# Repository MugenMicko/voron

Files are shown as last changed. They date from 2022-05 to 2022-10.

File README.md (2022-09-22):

# Voron Mods

These are mods that I have designed for my V0.1 and Trident.

I hope you find some of them useful:

## [Dragon Burner Toolhead](V0/Dragon_Burner)
V0.1 Toolhead using 2 4010 part cooling fans and a 3010 fan for most hotends including the Dragon High Flow, Rapido High Flow and Revo Voron

## [Rapid Burner Toolhead](V0/Rapid_Burner)
V0.1 Toolhead has been specifically designed for the Rapido UHF and Dragon UHF hotends and uses 2 4010 part cooling fans and a 3010 hotend fan

## [MailBox Toolhead](V0/5015_Toolhead)
V0.1 Toolhead using 1 5015 part cooling fans and a 3010 fan for most hotends including the Dragon High Flow, Rapido High Flow and Revo Voron

## [RoundHouse Extruder](general/RoundHouse)
V0.1 Extruder to complement the 5015 Toolhead using BMG parts

## [RoundAbout Extruder](general/RoundAbout)
V0.1 Extruder to complement the 5015 Toolhead using Orbiter v2.0 parts

## [NozzleWiper](V0/NozzleWiper)
V0.1 Nozzle purge and wipe mod

## [TipTophat](V0/TipTophat)
V0.1 Alternative Tophat for the Voron v0.1 which uses the BOM panels

## [RunoutUnklicky](general/RunoutUnklicky)
Runout UnKlicky Sensor is a filament runout sensor

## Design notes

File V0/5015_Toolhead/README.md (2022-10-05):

# 5015 Toolhead v4 (The Mailbox)

This is a Voron V0.1 toolhead that uses the guts of a 5015 fan for part cooling and incorporates Neopixel RGBW leds. It currently works with the LGX Lite extruder, the [Voron PocketWatch 2](https://github.com/VoronDesign/Pocket-Watch) and the [RoundHouse](https://github.com/waytotheweb/voron/tree/main/general/RoundHouse) and the [RoundAbout](https://github.com/waytotheweb/voron/tree/main/general/RoundAbout) extruders designed specifically for this hotend.

It uses the standard Voron V0.1 X carriage (and the MGN9C mod X carriage), is inspired by the [Mini-AfterSherpa](https://github.com/KurioHonoo/Mini-AfterSherpa).

This toolhead should not lose any X, Z travel. Y axis loss depends on the hotend and bed positioning. The Revo Voron losing none, but larger hotends losing up to ~3mm.

5015_Toolhead
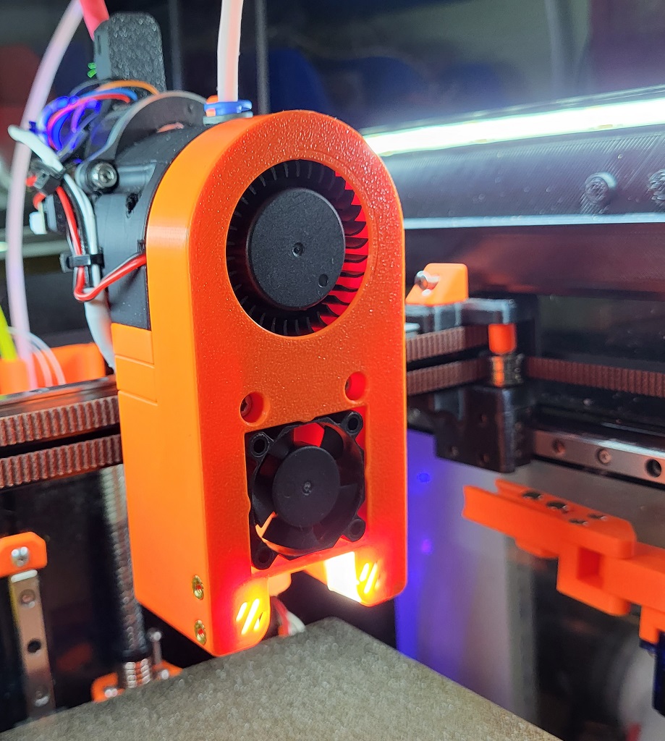
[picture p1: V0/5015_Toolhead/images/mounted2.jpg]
mounted2


### v4 - Front:
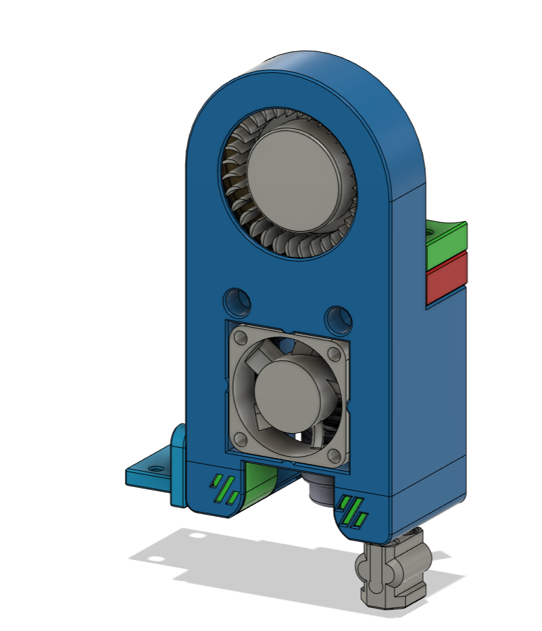
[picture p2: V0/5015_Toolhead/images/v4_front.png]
v4_front


### v4 - Back:
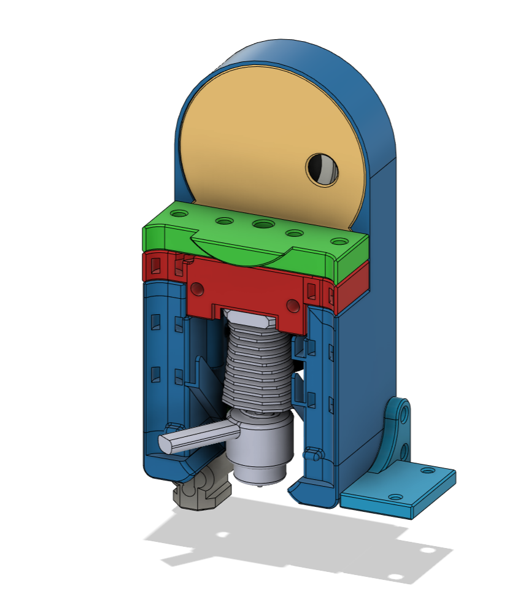
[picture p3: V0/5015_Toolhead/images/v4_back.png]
v4_back


Computation Fluid Dynamics results:

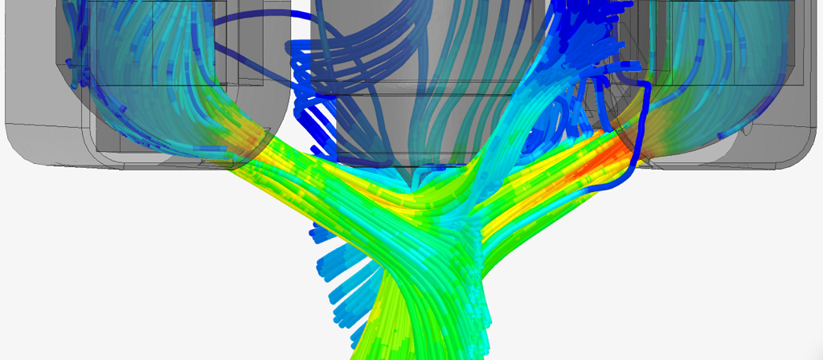
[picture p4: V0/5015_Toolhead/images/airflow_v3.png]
airflow


## Printing:

- Use the Voron defaults and print in ABS or better
- The parts are orientated correctly in the STLs
- The cowl has different variants for choice of probe, or no probe
- Choose the mount for the specific hotend to be used
- If using the [Voron Pocket-Watch 2](https://github.com/VoronDesign/Pocket-Watch) extruder, print the source STL's from the repository, but use the [Guts_p2_x1.stl](STLs/Guts_p2_x1.stl) from this project instead. The Pocket-Watch is [inverted for this toolhead](images/PocketWatch2.jpg). (Note: The PTFE tube will likely pop out of the top of extruder when fully unloading filament as there is no room for the tube retainer)

## BOM:

- 2x M3x35mm SHCS/BHCS (2 for the X carriage mount)
- 2x M3x20mm  SHCS/BHCS (for the hotend/extruder mount)
- 2(4)x Brass heat inserts (2 for cowl hotend mount, 2 optional for ADXL mount)
- 1x 5015 part cooling fan that you are happy to cut to pieces
- 1x 3010 hotend fan (24v recommended)
- 2x Neopixels and wiring (optional)

The cowl variants support a no probe setup, [SlideSwipe magnetic probe](https://github.com/chestwood96/SlideSwipe), [ZeroClick probe](https://github.com/zruncho3d/ZeroClick), [(Un)Klicky Probe](https://github.com/jlas1/Klicky-Probe) and a MiniSlideSwipe using the SlideSwipe mechanism

## Supported Hotends:

- Revo Voron
- Dragon SF/HF
- DragonFly
- Rapido HF / Mellow Crazy Dragon / Dragon UHF (without extender)
- Mellow NF Crazy (/Mozzie)

## Fans:

I am using these fans:

- 24v Blower 5015: [Gdstime](https://www.aliexpress.com/item/32867546212.html)
- 24v Axial 3010: [Gdstime](https://www.aliexpress.com/item/1005002857100082.html)

## Heatsink Thermistor:

Each cowl includes a hole at the top to insert a thermistor. With this in place, klipper can track the temperature of the heatsink to watch for heat creep from the heatbreak. You can have klipper abort and shutdown before your whole toolhead melts! You only need a simple klipper entry for the appropriate pin on your MCU, e.g.:

```
[temperature_sensor Heatsink]
sensor_type: Generic 3950
sensor_pin: expander:PA5
max_temp: 85
```

Klipper will shutdown if the top of the heatsink hits 85C. You can use thermal paste to help keep a bulb thermistor in contact with the heatsink and route the wires through the provided groove, then fit the extruder on top to hold it in place.

## Assembly:

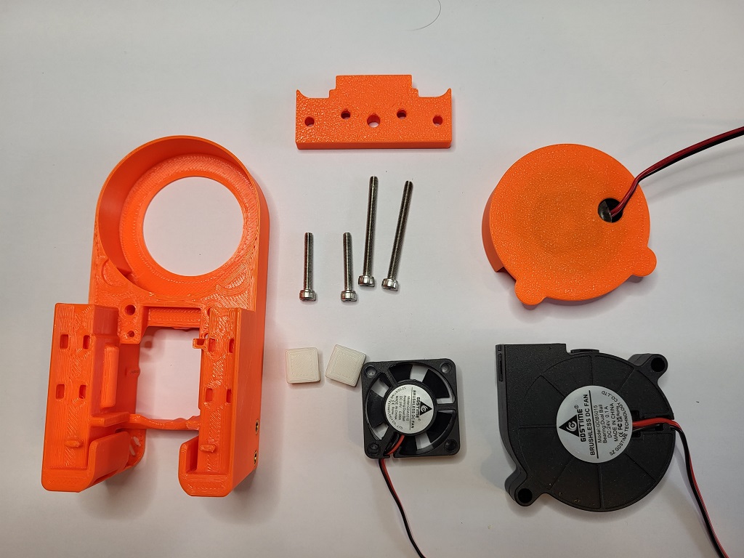
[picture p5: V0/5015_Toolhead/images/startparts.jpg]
startparts


Place brass inserts into the cowl for mounting the hotend and the adxl mount if using this.

Remove the fan duct supports carefully. Check that none of the removed plastic has fallen into the ducts:

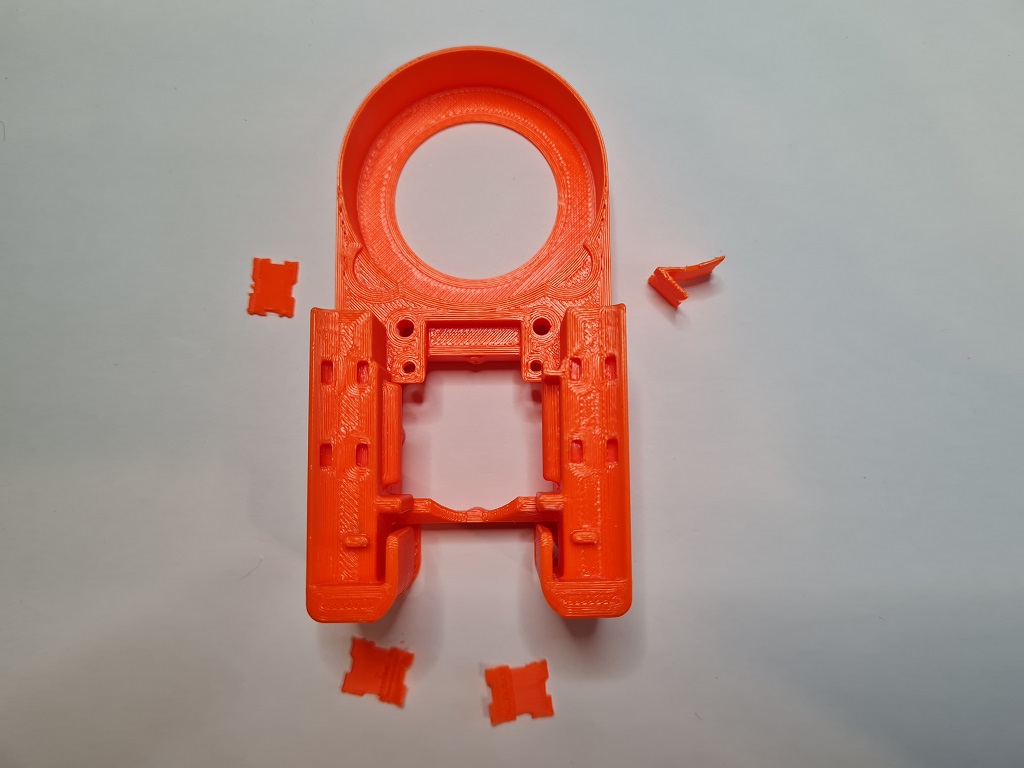
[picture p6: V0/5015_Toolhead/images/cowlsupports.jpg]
cowlsupports

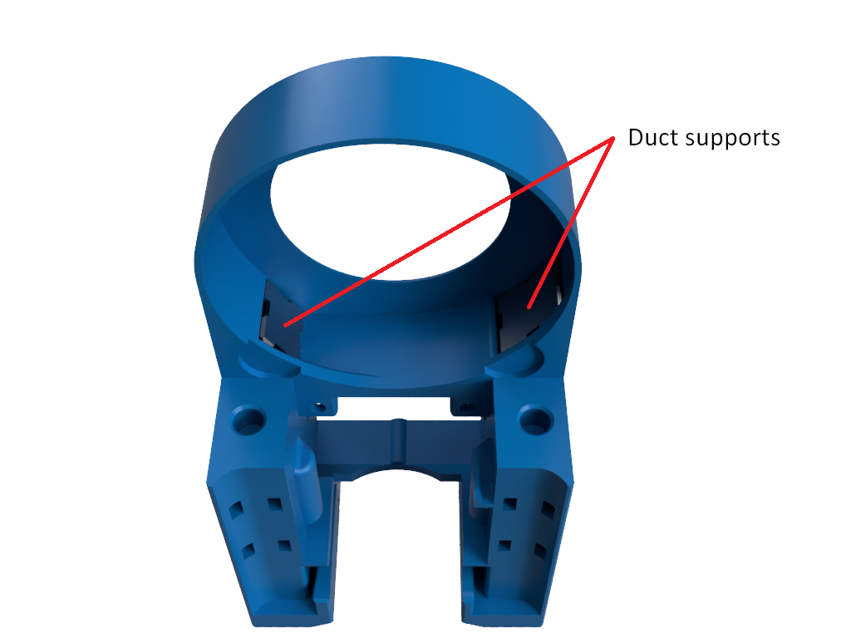
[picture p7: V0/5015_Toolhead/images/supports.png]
supports


The 3010 hotend fan is meant to be press fit. If it's too tight, sand or file the opening but don't force it in otherwise it can deform and the blades will hit the casing. If it's too lose or rattles, use M3 screws to secure it through the top two holes into the cowl. Routing of the fans cables are through the channel provided:

hotendfan
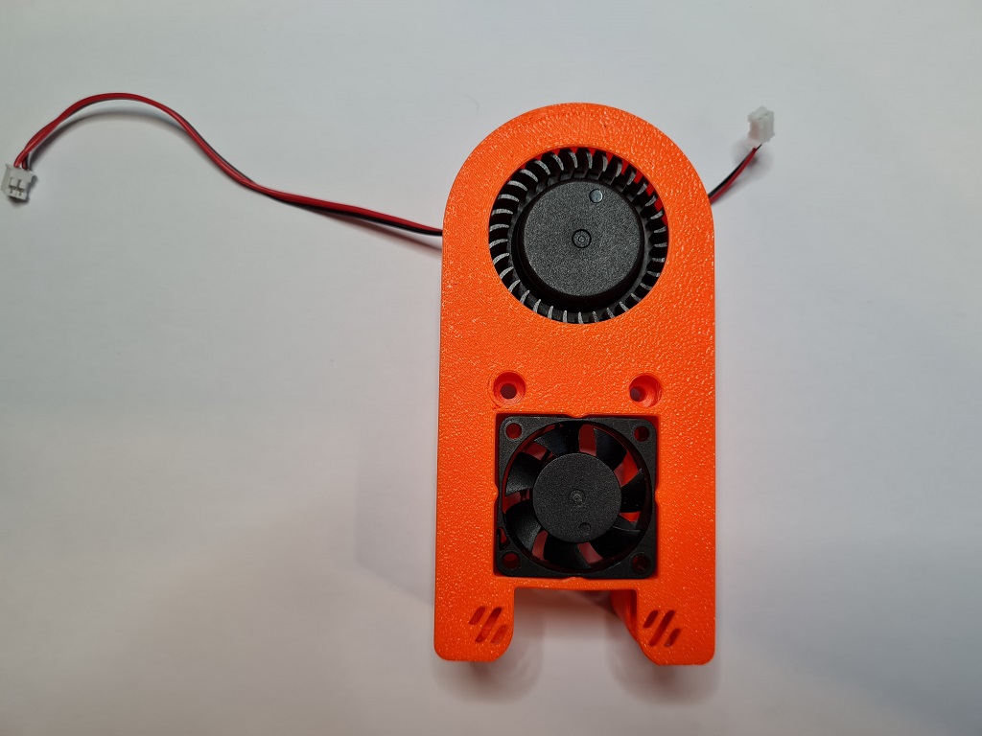
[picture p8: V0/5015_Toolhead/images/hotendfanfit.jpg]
hotendfanfit


You need to remove most of the outer shell of the 5015 fan. Before doing so, please connect the fan to your MCU/toolhead board and ensure that it responds to pmw from klipper.

You need to split the 5015 fan casing in half by poking the tabs on the fan. Once done, take the half with the fan attached and carefully trim off the casing up to the fins. I use side cutters, but a craft knife should work. If more breaks off it shouldn't be a problem. What you want to be left with is a ~35mm circle of casing that matches the diameter of the actual fan. Be very careful not to cut the fan wires, or to manipulate the wires too much as they can easily break from their solder patches (a dab of hot glue helps):

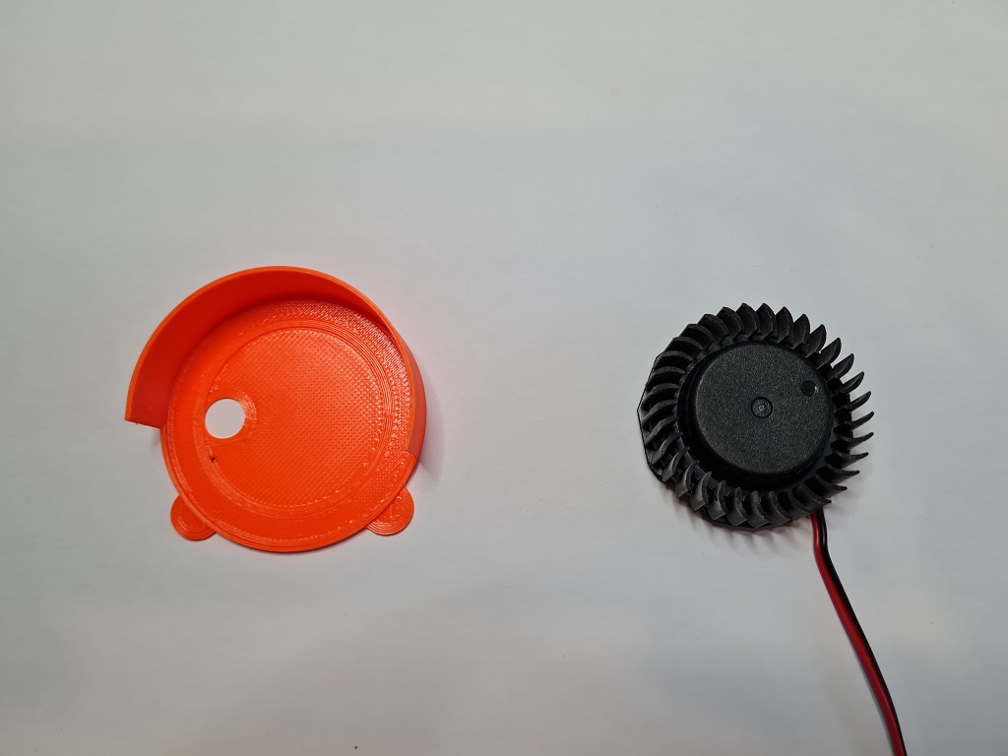
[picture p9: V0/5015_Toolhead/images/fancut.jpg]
fancut


Using VHB tape, cut to fit the back of the fan. You might want to remove any stickers on the back of the fan casing to ensure a good bond:

fantape

Affix the fan to the fan cap by threading the wires through the hole and centre the fan into the middle of the fan cap. It does not need to be 100% central, but the closer the better it will look:

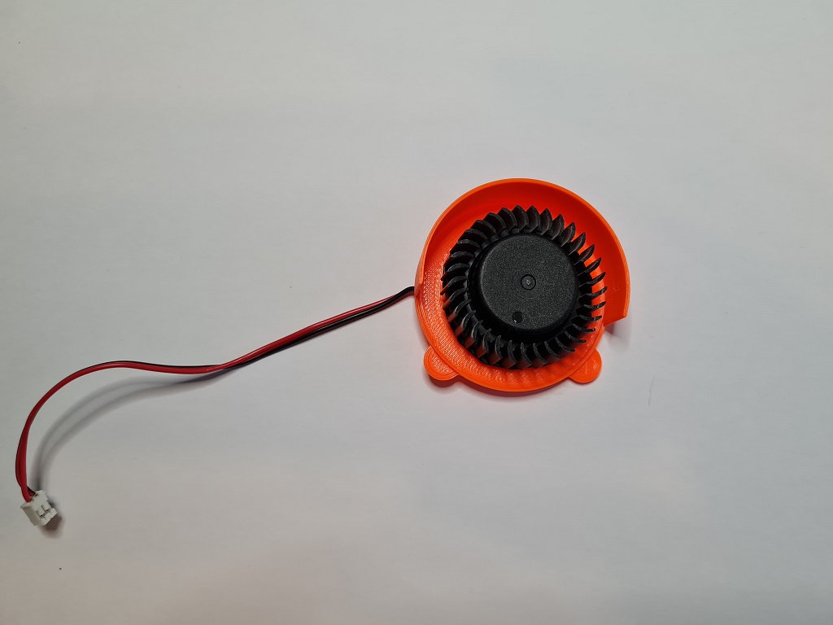
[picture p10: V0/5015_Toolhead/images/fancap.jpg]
fancap


Fit the fan cap onto the cowl and ensure that it sits well without rubbing on the cowl:

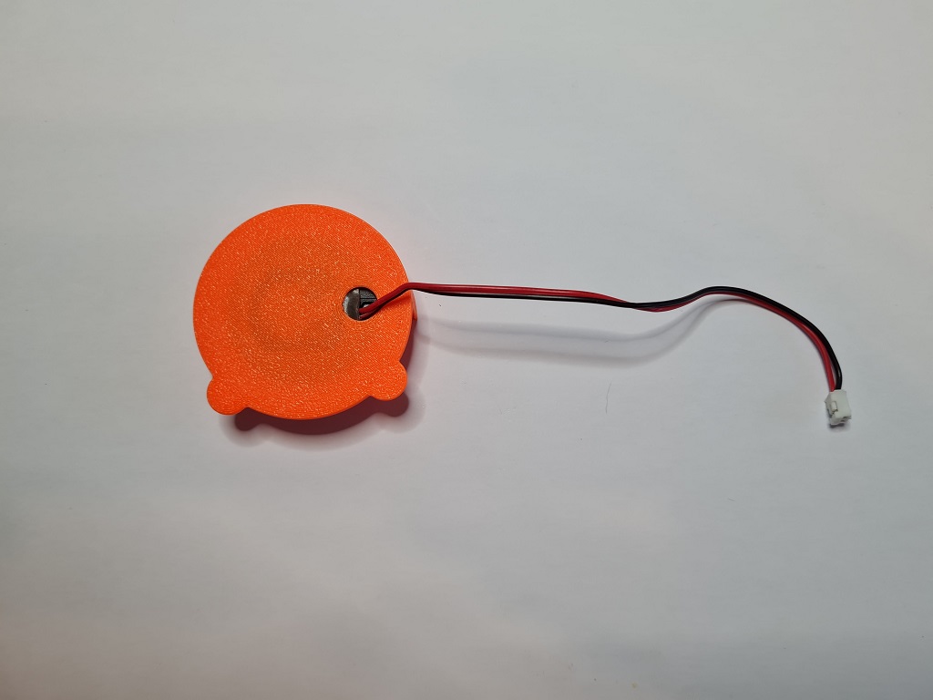
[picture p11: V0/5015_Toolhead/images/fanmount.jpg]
fanmount


The fan cover is a light friction fit and is held in place by the extruder mount:

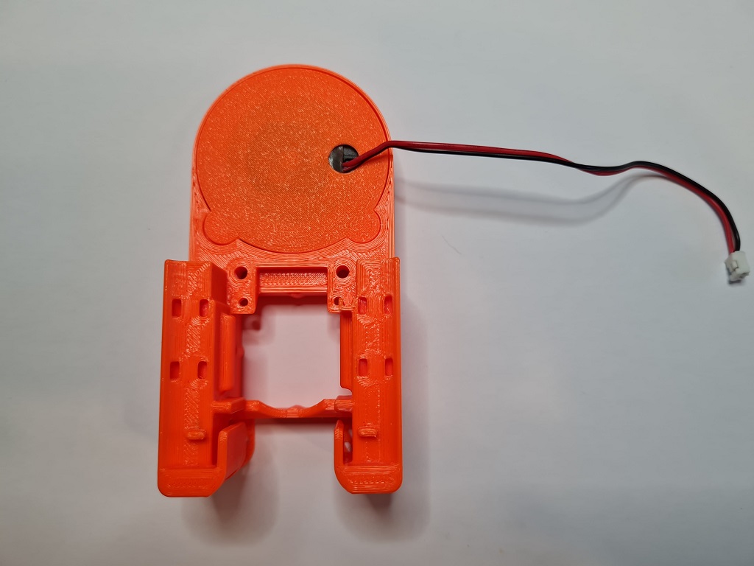
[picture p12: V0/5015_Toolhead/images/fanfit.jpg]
fanfit


If you are going to use Neopixels, remove the two tabs at the inner base of the cowl to expose the Neopixel holes:

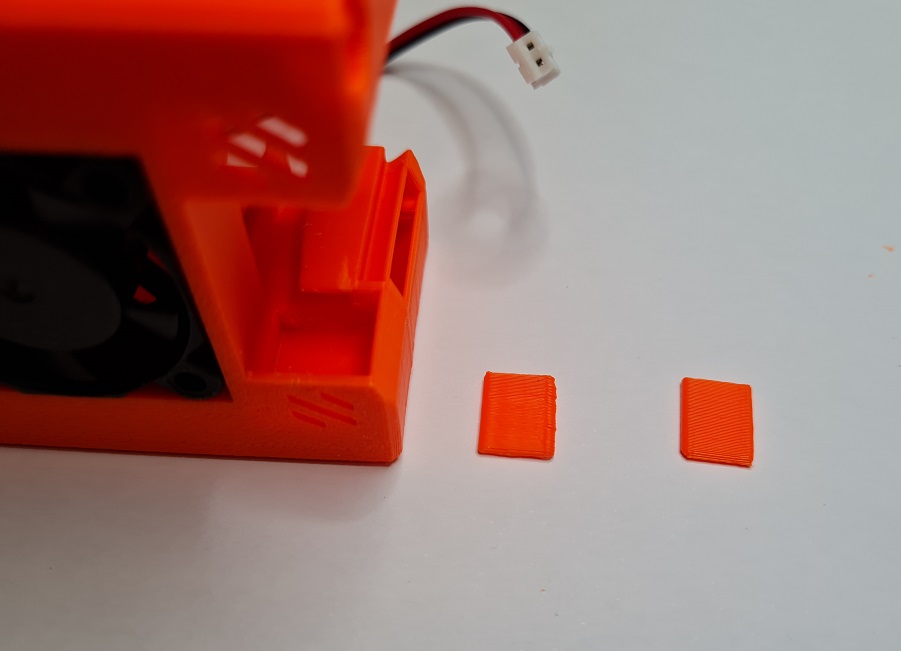
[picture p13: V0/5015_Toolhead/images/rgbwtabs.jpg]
rgbwtabs


Route the Neopixel cable through the provided groove and align with the hole:

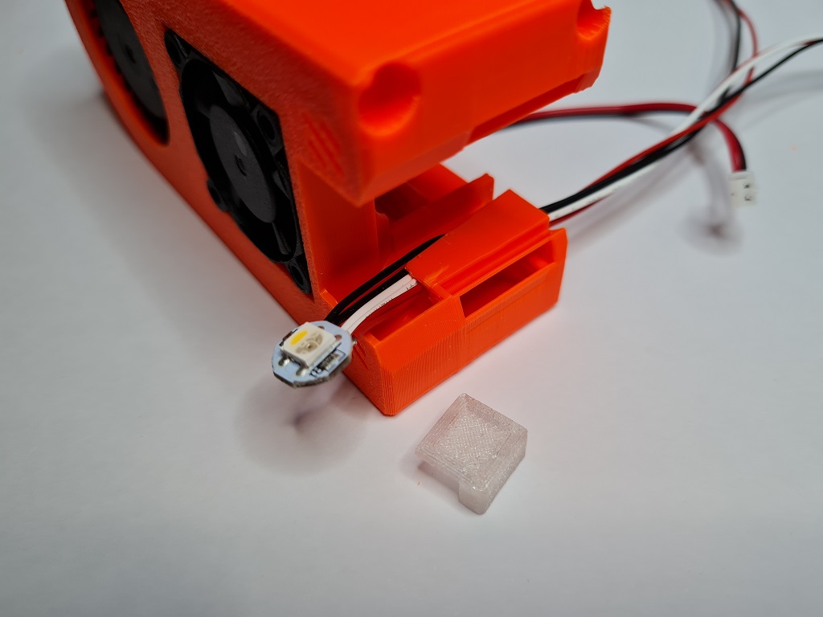
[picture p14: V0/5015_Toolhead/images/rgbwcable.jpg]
rgbwcable


Place the Neopixel diffuser/holder over the top of the Neopixel with the longer sides facing down and the front:

rgbwdiffuser

Push the diffuser/holder into the whole being careful not to dislodge the Neopixel being careful not to leave the cables pinched:

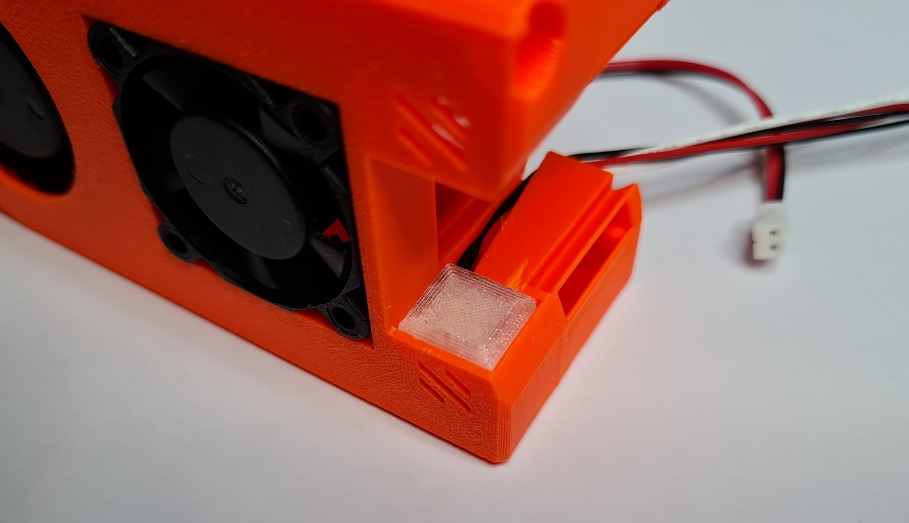
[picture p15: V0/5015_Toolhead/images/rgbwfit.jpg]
rgbwfit


Affix your chosen hotend mount to your hotend:

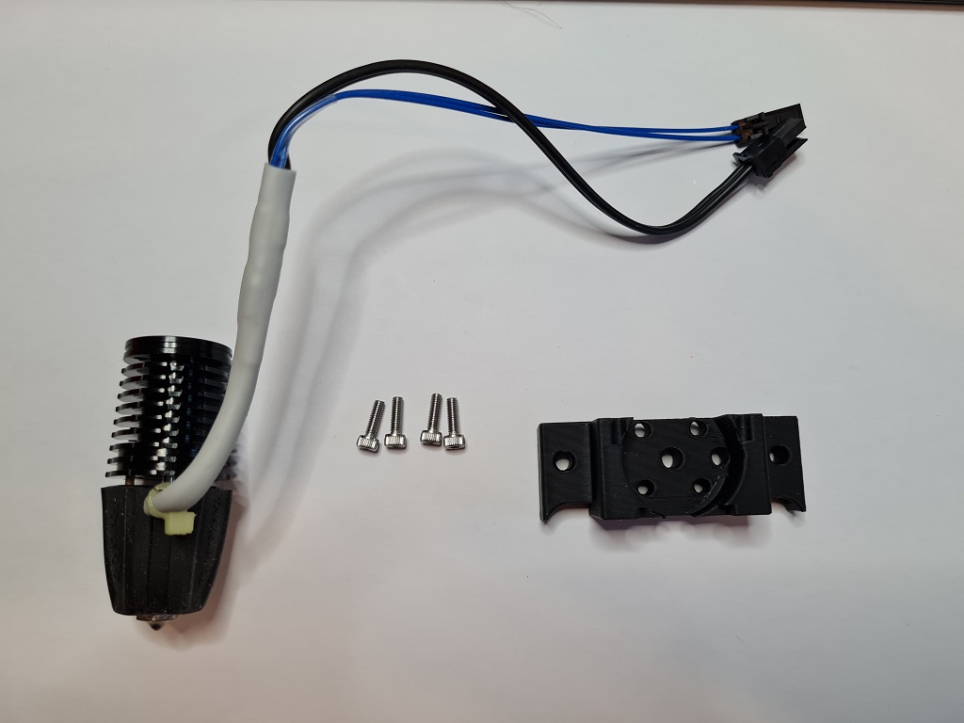
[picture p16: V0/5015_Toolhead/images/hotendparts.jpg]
hotendparts

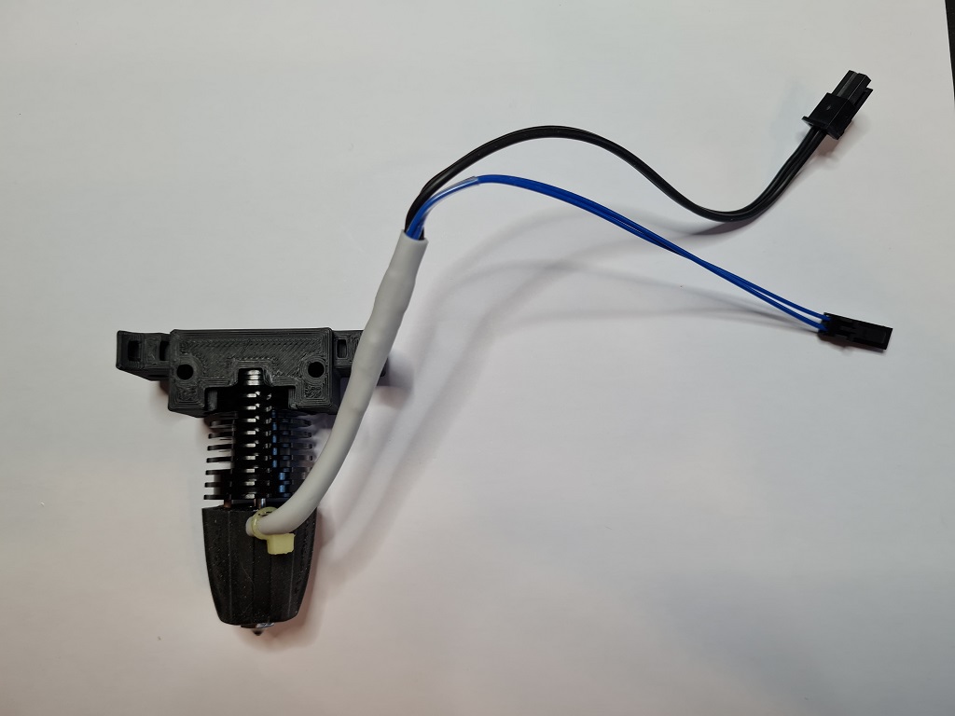
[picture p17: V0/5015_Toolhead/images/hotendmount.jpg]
hotendmount


Affix the extruder mount to the bottom of the extruder:

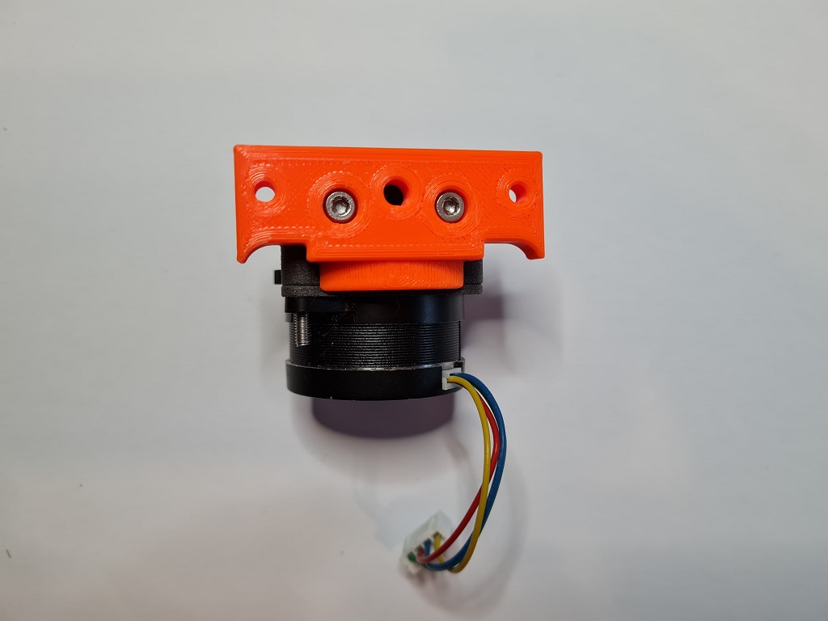
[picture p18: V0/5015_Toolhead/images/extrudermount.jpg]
extrudermount


Mount the extruder on top of the hotend onto the cowl using 2 M3x20 screws to check the assembly:

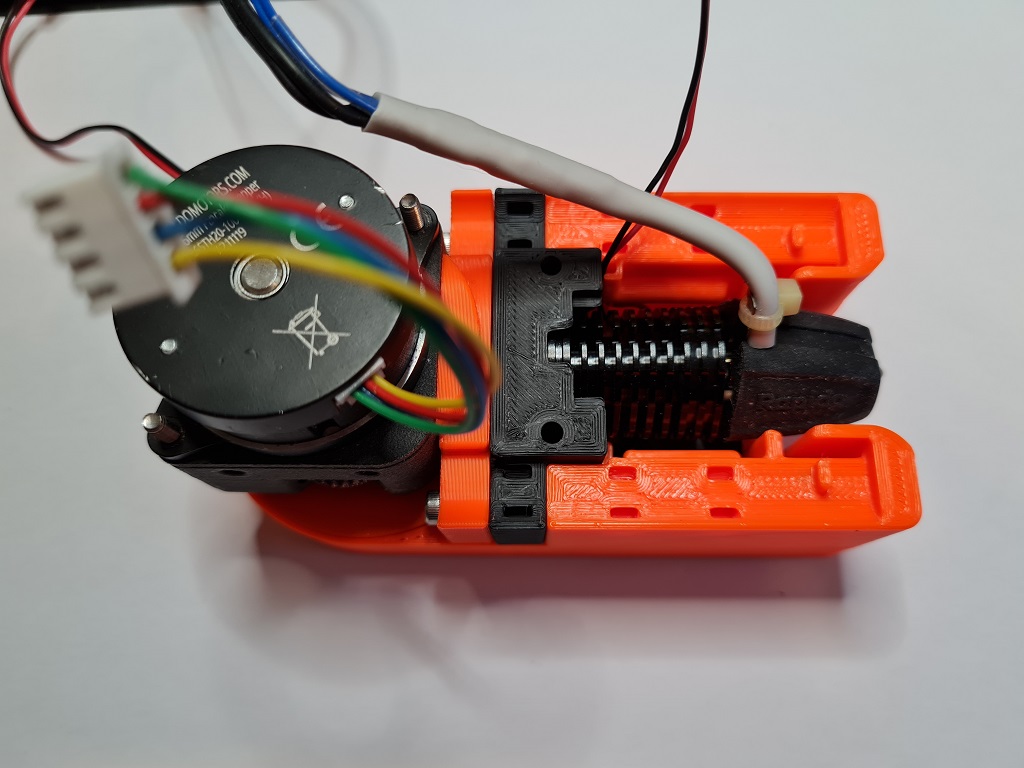
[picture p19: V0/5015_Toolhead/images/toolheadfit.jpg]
toolheadfit


You can now route your cables and secure them to the cable-tie mounts provided.

The following is a complete installation with the [RoundHouse](https://github.com/waytotheweb/voron/tree/main/general/RoundHouse) extruder and a custom hotend:

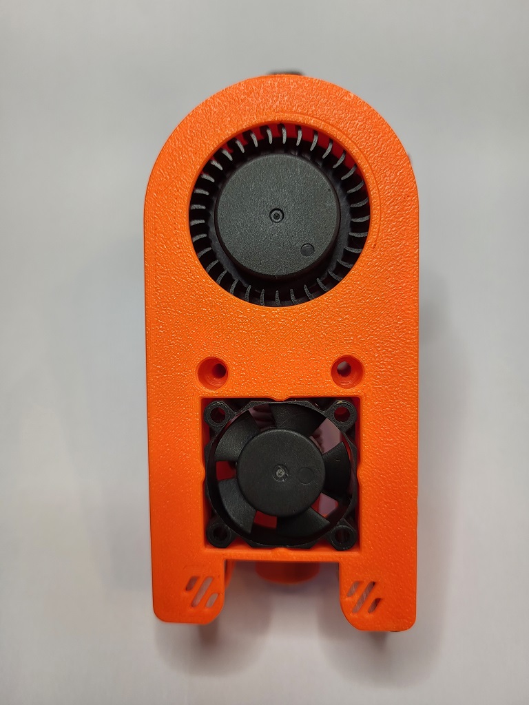
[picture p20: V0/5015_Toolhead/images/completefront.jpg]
completefront


Neopixel cable routing can be seen on these two images:

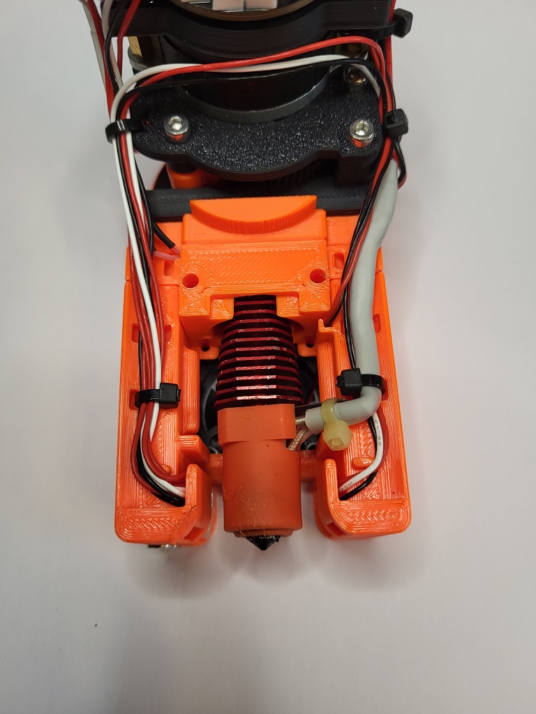
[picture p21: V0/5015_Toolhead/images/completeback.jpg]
completeback

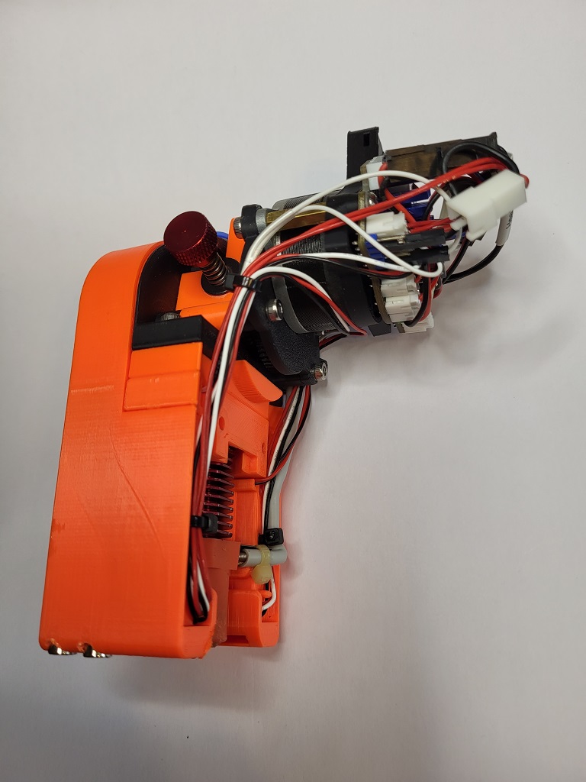
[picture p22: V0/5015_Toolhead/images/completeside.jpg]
completeside


Offer up the cowl and extruder assembly to the X carriage and secure using 2 M3x35mm screws. Be careful not to catch any wires between the surfaces and that when the toolhead moves the X and Y axis endstops are triggered. Also check that the X axis can move completely to the left:

mounted3

Zip-tie the wires at the back of the assembly.

Plugin, test the fans and redo your X offset as it will have changed slightly.

## Neopixels:

Make sure the cables interconnecting the two Neopixels is long enough to loop up both sides of the cowl and above the extruder mount at the rear:
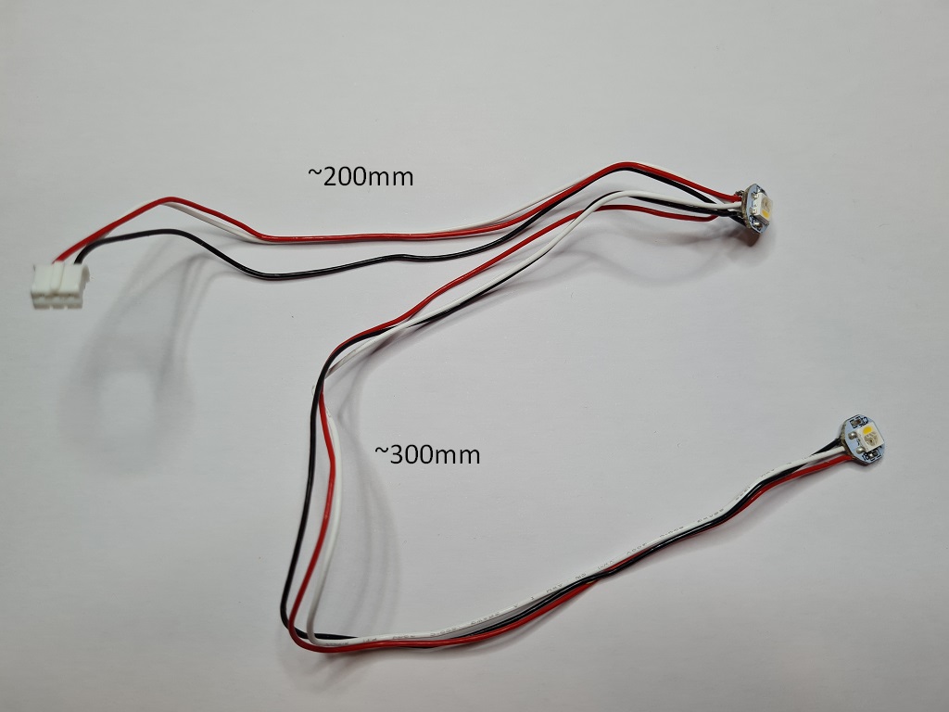
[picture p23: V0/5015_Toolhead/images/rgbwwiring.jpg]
rgbwwiring


For creating the actual wiring, refer to page 46 of the [StealthBurner manual](https://github.com/VoronDesign/Voron-Stealthburner/blob/main/Manual/Assembly_Manual_SB.pdf)

To configure the Neopixels in Klipper, I'd suggest using the [StealthBurner config file](https://github.com/VoronDesign/Voron-Stealthburner/blob/main/Firmware/stealthburner_leds.cfg) and change the following to assign the two Neopixels a wider range of colour options:

```
variable_logo_idx:              "1,2"
variable_nozzle_idx:            "3" # not used
```

## MiniSlideSwipe

This uses the standard [SlideSwipe magnetic probe](https://github.com/chestwood96/SlideSwipe) mechanism, but with a different probe.

There are 2 variants:

- Microswitch

This uses a BOM microswitch. Print [MiniSlideSwipe_Shuttle_Klicky.stl](STLs/MiniSlideSwipe_Shuttle_Klicky.stl). Solder a short piece of stripped wire on the two end posts on the microswitch. Pass the bare wires up into the magnet recesses and push in the microswitch. Push (optionally glue) two magnets with the same polarity into the shuttle.

- Unklicky

This uses a magnet and 2 M3x6mm SHCS/BHCS screws. Print [MiniSlideSwipe_Shuttle_Unklicky.stl](STLs/MiniSlideSwipe_Shuttle_Unklicky.stl) and [MiniSlideSwipe_Probe_Unklicky.stl](STLs/MiniSlideSwipe_Probe_Unklicky.stl). Push one magnet into the probe. Push the probe into the shuttle and partly screw in the M3x6mm SHCS/BHCS screws to the sides of the shuttle. Using 2 pieces of stripped wire, wrap one end around the screw and place the other into the corresponding magnet hole and then tighten up the screw. Repeat for the other side of the shuttle. Push (optionally glue) two magnets with the same polarity into the shuttle. The polarity of those 2 magnets must be the reverse of the probe magnet so that the probe should now move up and down as you press it.

- For both:

Use a multimeter and check for continuity. It should show continuity when the probe is not triggered and no continuity when the switch is pressed.

On the cowl, use two wires from inside the right LED mounting hole. Use coiled bare wire from the two pieces and thread the wire into the LED mounting hole and then push (optionally glue) the magnets into the base, ensuring that they have the correct polarity so that the shuttle probe will attach to them. Run the wires up the LED channel on the inside of the hotend cowl and attach as you would for a normal [SlideSwipe magnetic probe](https://github.com/chestwood96/SlideSwipe).

Once again, a multimeter and check for continuity. It should show continuity when the probe is attached to the hotend cowl but not triggered and no continuity when the switch is pressed.

## v1 Changelog:

- 2022-06-03 WIP release
- 2022-06-04 Added support for the Voron PocketWatch 2 extruder
- 2022-06-05 Added cable exit hole in Klicky cowl
- 2022-06-05 Added cable ducts to all cowls
- 2022-06-05 Moved zip-ties from cowls to hotend mounts
- 2022-06-07 Added Neopixel support
- 2022-06-08 Updated all STLs, images and docs
- 2022-06-11 Updated the assembly instructions
- 2022-06-13 Fixed the Revo Voron mount
- 2022-06-13 Added Rapido HF mount with no loss in Z
- 2022-07-03 Added ZeroClick support

## New version 2:

- Moved to Fusion 360
- Increased and improved airflow
- Improved heat warping protection around RGBW ducts
- Improved cable routing
- Improved RapidoHF support
- Improved hotend fan push fit
- Improved RGBW logo lighting
- Improved RGBW installation and wiring instructions
- 2 screw X carriage support (3rd screw was unnecessary)

## v2 Changelog:

- 2022-07-30 Version 2 release
- 2022-07-30 RoundHouse extruder release

## New version 3:

- Improved easy mounting using front screws
- Improved size with an reclaimed 1mm on the Y axis (it all counts!)
- Improved cable routing
- Improved RapidoHF support
- Improved fan cover
- Improved airflow using CFD for the part cooling ducts
- Improved RGBW install and routing
- New MiniSlideSwipe probe (for use with SlideSwipe)
- Improved ZeroClick support
- Improved heatbreak temperature sensor routing
- Improved built-in supports

## v3 Changelog:

- 2022-08-15 Version 3 release

## New version 4:

- Improved LED cable routing
- Modified part cooling ducts provide more space for with wide hotends and long
  heater cartridges, e.g. Dragonfly
- Improved LED covers and fitting
- Improved LED housing geometry to improve print quality
- New Mellow NF Crazy (/Mozzy) hotend mount

## v4 Changelog:

- 2022-09-16 Version 4 release
- 2022-09-22 Released bowden mount with strain relief and PCB mount
- 2022-09-25 Updated Dragon Mount. Increased depth to better cater for X carriage screws
- 2022-10-05 Added MiniSlideSwipe documentation

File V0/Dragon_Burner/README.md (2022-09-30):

# Dragon Burner v2
I wanted to improve the cooling of the Dragon HF hotend and provide improved part cooling when printing filament that needs it (e.g. PLA). I designed this toolhead to use 2 4010 blower fans for part cooling and a 3010 fan for hotend cooling.

It uses the standard Voron X carriage, and is inspired by the [Mini-AfterSherpa](https://github.com/KurioHonoo/Mini-AfterSherpa)

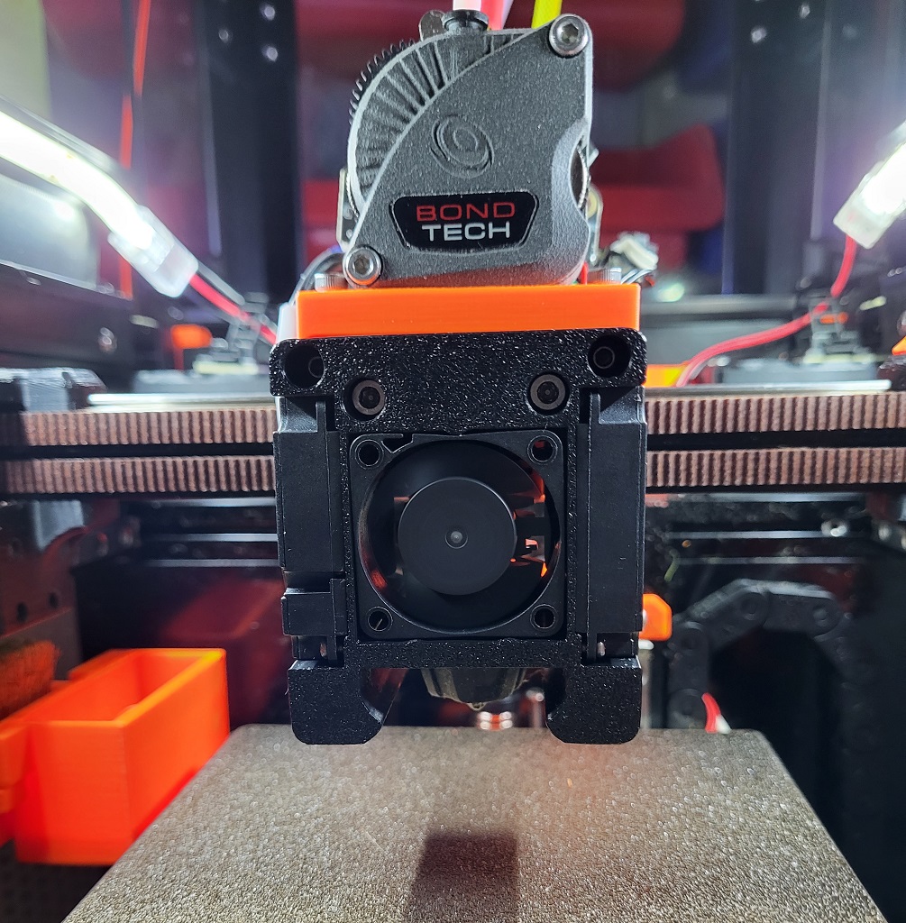
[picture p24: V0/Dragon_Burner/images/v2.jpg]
Dragon Burner

Dragon Burner

## Features:

### Hotend support:
- Dragon SF and HF hotend support
- Dragonfly hotend support
- Revo Voron hotend support
- Rapido HF hotend support
- NF Crazy hotend support

### Extruder support:
- LGX Lite extruder support
- Mini Sherpa extruder support
- Sailfin/Sharkfin extruder support
- Orbiter v1.5 extruder support
- Orbiter v2 extruder support
- [RoundHouse extruder](https://github.com/waytotheweb/voron/tree/main/general/RoundHouse) support

### Fan support:
- Single 3010 24v hotend cooling fan
- Twin 4010 24v blower part cooling fans
- Screwless hotend fan attachment

### Probe support:
- [SlideSwipe magnetic probe](https://github.com/chestwood96/SlideSwipe) support
- [(Un)Klicky Probe](https://github.com/jlas1/Klicky-Probe) support
- [ZeroClick probe](https://github.com/zruncho3d/ZeroClick) support

### Extras:
- ADXL345 mount point and board mount
- Heatsink thermistor support

## Printing:

- Use the Voron defaults and print in ABS or better. The parts are orientated correctly in the STL.
- Print the appropriate cowl for your sensor probe if you use one
- Print the appropriate hotend mount
- Print the extruder mount

Note: If using an Orbiter v1.5 extruder, you will need the extruder mount and the hotend mounts from the [STL Orbiter1.5 subdirectory](STLs/Orbiter1.5). With this extruder you loose the addition of the heatbreak thermistor.

Note: If using an Orbiter v2 extruder, you will need the extruder mount and the hotend mounts from the [STL Orbiter2 subdirectory](STLs/Orbiter2).

## BOM:

- 2x M3x35mm SHCS/BHCS (2 for the X carriage mount)
- 6x M3x5x4mm heat inserts (4 for extruder mount, optional: 2 for ADXL mount)
- 2x M3x35mm SHCS/BHCS (2 for the X carriage mount)
- 6x M3x8mm SHCS/BHCS (4 for extruder mount, optional: 2 for ADXL mount)
- 2x M2x10mm self tapping screws (for blower fans)
- 2x M2x8mm BHCS and nuts (optional: to mount ADXL)
- 2x 4010 blower fans (24v recommended)
- 1x 3010 hotend fan (24v recommended)

The cowls support a no probe setup, [SlideSwipe magnetic probe](https://github.com/chestwood96/SlideSwipe), [(Un)Klicky Probe](https://github.com/jlas1/Klicky-Probe) and [ZeroClick probe](https://github.com/zruncho3d/ZeroClick)

## Fans:

I am using these fans:

- 24v Axial 3010: [Gdstime](https://www.aliexpress.com/item/1005002857100082.html)
- 24v Blower 4010: [Gdstime](https://www.aliexpress.com/item/32799324058.html)

## Heatsink Thermistor:

Each cowl includes a hole at the top to insert a thermistor. With this in place, klipper can track the temperature of the heatsink to watch for heat creep from the heatbreak. You can have klipper abort and shutdown before your whole toolhead melts! You only need a simple klipper entry for the appropriate pin on your MCU, e.g.:

```
[temperature_sensor Heatsink]
sensor_type: Generic 3950
sensor_pin: expander:PA5
max_temp: 85
```

Klipper will shutdown if the top of the heatsink hits 85C. You can use thermal paste to help keep a bulb thermistor in contact with the heatsink and route the wires through the provided groove, then fit the extruder on top to hold it in place.

## Assembly:

startparts

Add heat inserts into the cowl and hotend mount:

heatinserts

Insert the fans. You will need to release the cable from their tabs on the front-end and one of the 4010 fans. This is to allow the cables to be routed correctly. Care should be taken with the cables after doing this as too much movement could break off the wires from the fans.

Fit the 4010 fan that you released the cable from into the cowl, passing the cable through the provided round hole:

fitleftfan

The 3010 hotend fan is meant to be press fit. If it's too tight, sand or file the opening but don't force it in otherwise it can deform and the blades will hit the casing. If it's too lose or rattles, use M3 screws to secure it through the top two holes into the cowl. Routing of the fans cables are through the channel provided:

fitfrontfan

Now slot in the second 4010 fan and use 2x M2x10mm self tapping screws to secure the fans into the cowl:

frontfans

Place the hotend onto the cowl. There are two locator tabs to help align the two parts. From the front use 2 M3x8mm screws to secure the cowl and the hotend mount together:

fithotend

Attach the extruder mount to your chosen extruder, shown here with the LGX Lite:

extrudermount

Mount the extruder to the hotend mount:

frontview
sideview

Offer up the cowl and extruder assembly to the X carriage and secure using 2 M3x35mm screws. Be careful not to catch any wires between the surfaces and that when the toolhead moves the X and Y axis endstops are triggered. Also check that the X axis can move completely to the left:

Zip-tie the wires at the back of the assembly.

Plugin, test the fans and redo your X offset as it will have changed slightly.

## v1 Changelog:

- 2022-04-12 First release
- 2022-04-12 Fixed issue with incorrect part placement
- 2022-04-13 Added mounts for the Dragonfly hotend
- 2022-04-13 Added mounts for the Rapido HF hotend
- 2022-04-13 Fixed clearance to socks on Rapido and Dragonfly
- 2022-04-16 Fixed misalignment of filament tube hole for Dragonfly
- 2022-04-16 New ducts improve airflow over nozzle
- 2022-04-19 New ducts improve airflow direction
- 2022-04-19 Added hole and wire groove for heatsink thermistor
- 2022-04-21 Added Klicky variant support
- 2022-04-21 Reorganised repo to separate hotends
- 2022-04-21 Added screwless 3010 hotend fan mount
- 2022-04-27 Added mounts for the E3D Revo Voron hotend
- 2022-05-07 Added wire exit for Klicky mount for all hotends
- 2022-05-08 Modified all toolheads to use removeable fan ducts
- 2022-05-10 Links to public Tinkercad added
- 2022-05-11 Updated Klicky fan ducts
- 2022-05-21 Added bridging supports to Klicky fan ducts
- 2022-06-03 Added ZeroClick variant support
- 2022-06-05 Easier to print fan ducts and magnet helper for ZeroClick

## Release v2:

- Redesigned in Fusion 360
- Integrated fan ducts
- Separate hotend mounts
- Redesigned part cooling fan ducts using CFD
- Significantly better airflow for part cooling
- Improved cable routing
- Improved documentation (with pictures!)
- Improved printability of all parts
- Improved duct design to provide more space for heater cartridges
- Improved support for RapidoHF

## v2 Changelog:

- 2022-08-27 v2 released
- 2022-08-28 Made a little more space for cabling
- 2022-08-28 Added NF Crazy mount and cowl changes (untested)
- 2022-08-28 Added Orbiter v2 support - mount and hotend mounts (untested)
- 2022-08-29 Added Orbiter v1.5 support - mount and hotend mounts (untested)
- 2022-09-21 Fixed ZeroClick cowl mount
- 2022-09-22 Released bowden mount
- 2022-09-25 Updated Dragon Mount. Increased depth to better cater for X carriage screws
- 2022-09-30 Updated all cowlings to help fix screws loosening over time

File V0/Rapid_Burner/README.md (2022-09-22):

# Rapid Burner (Beta Release)
This toolhead for the Voron v0.1 has been specifically designed for the Rapido UHF and Dragon UHF hotends.

It uses the standard Voron X carriage, and is inspired by the [Mini-AfterSherpa](https://github.com/KurioHonoo/Mini-AfterSherpa)

Rapid Burner
Rapid Burner

## Features:

### Hotend support:
- Rapido UHF hotend
- Dragon UHF hotend

### Extruder support:
- LGX Lite extruder support
- Mini Sherpa extruder support
- Sailfin/Sharkfin extruder support
- Orbiter v1.5 extruder support
- Orbiter v2 extruder support
- [RoundHouse extruder](https://github.com/waytotheweb/voron/tree/main/general/RoundHouse) support

### Fan support:
- Single 3010 24v hotend cooling fan
- Twin 4010 24v blower part cooling fans
- Screwless hotend fan attachment

### Probe support:
- [SlideSwipe magnetic probe](https://github.com/chestwood96/SlideSwipe) support
- [(Un)Klicky Probe](https://github.com/jlas1/Klicky-Probe) support
- [ZeroClick probe](https://github.com/zruncho3d/ZeroClick) support

### Extras:
- ADXL345 mount point and board mount

## Printing:

- Use the Voron defaults and print in ABS or better. The parts are orientated correctly in the STL.
- Print the appropriate cowl for your sensor probe if you use one
- Print the appropriate hotend mount
- Print the extruder mount if needed

## BOM:

- 2x M3x20mm SHCS/BHCS (2 for the X carriage mount)
- 6x M3x5x4mm heat inserts (4 for extruder mount, optional: 2 for ADXL mount)
- 6x M3x8mm SHCS/BHCS (4 for extruder mount, optional: 2 for ADXL mount)
- 2x M2x10mm self tapping screws (for blower fans)
- 2x M2x8mm BHCS and nuts (optional: to mount ADXL)
- 2x 4010 blower fans (24v recommended)
- 1x 3010 hotend fan (24v recommended)

The cowls support a no probe setup, [SlideSwipe magnetic probe](https://github.com/chestwood96/SlideSwipe), [(Un)Klicky Probe](https://github.com/jlas1/Klicky-Probe) and [ZeroClick probe](https://github.com/zruncho3d/ZeroClick)

## Fans:

I am using these fans:

- 24v Axial 3010: [Gdstime](https://www.aliexpress.com/item/1005002857100082.html)
- 24v Blower 4010: [Gdstime](https://www.aliexpress.com/item/32799324058.html)

## Assembly:

For detailed photos, see the [Dragon Burner](https://github.com/waytotheweb/voron/tree/main/V0/Dragon_Burner) instructions. Be aware that mounting the cowl to the X carriage is different with this toolhead.

Add heat inserts into the cowl and hotend mount.

Insert the fans. You will need to release the cable from their tabs on the front-end and one of the 4010 fans. This is to allow the cables to be routed correctly. Care should be taken with the cables after doing this as too much movement could break off the wires from the fans.

Fit the 4010 fan that you released the cable from into the cowl, passing the cable through the provided round hole.

The 3010 hotend fan is meant to be press fit. If it's too tight, sand or file the opening but don't force it in otherwise it can deform and the blades will hit the casing. Routing of the fans cables are through the channel provided.

Now slot in the second 4010 fan and use 2x M2x10mm self tapping screws to secure the fans into the cowl.

Mount the extruder to the hotend mount.

The hotend mount now needs to be mounted to the X Carriage using 2x M3x20mm screws.

Offer the cowl to the hotend mount and from the front use 2 M3x8mm screws to secure the cowl and the hotend mount together.

Be careful not to catch any wires between the surfaces and that when the toolhead moves the X and Y axis endstops are triggered. Also check that the X axis can move completely to the left:

Zip-tie the wires at the back of the assembly.

Plugin, test the fans and redo your X offset as it will have changed.

## v1 Changelog:

- 2022-09-04 First beta release
- 2022-09-21 Fixed ZeroClick cowl
- 2022-09-22 Released bowden mount

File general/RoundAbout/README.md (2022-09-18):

# RoundAbout Direct Extruder

The RoundAbout is a direct drive extruder designed for the Voron v0.1 that uses the guts of an Orbiter v2.0

It uses the mounts from the [Mini-AfterSherpa](https://github.com/KurioHonoo/Mini-AfterSherpa) and was designed to complement the [5015 Toolhead](https://github.com/waytotheweb/voron/tree/main/V0/5015_Toolhead) toolhead. It can be used on any toolhead that uses the [Mini-AfterSherpa](https://github.com/KurioHonoo/Mini-AfterSherpa) design.

orbfront

Please Note: This is a Work In Progress and things will likely change as issues are fixed and enhancements are made.

## Printing:

- Use the Voron defaults and print in ABS or better
- The parts are orientated correctly in the STLs

## BOM:

- 8x Brass heat inserts (6 for the front, 2 for the support ring)
- 1x Orbiter v2 Extruder
- 1x NEMA14 36mm pancake Motor with 10 tooth gear
- 1x UM2 Collet (optional)

## Sources:

- Orbiter v2 internals which you'll probably need a complete extruder to dismantle
- UM2 Embedded Collet, e.g. [E3D](https://e3d-online.com/products/embedded-bowden-collet-for-metal-1-75mm)

## CAD:

Will be published once released from WIP.

## Assembly:

Instructions to follow...

frontinserts

supportringinserts

latch

orbback

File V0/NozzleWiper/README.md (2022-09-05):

# Nozzle Wiper v2

This is a nozzle purge and wipe mod for the Voron V0.1. It is based on the [SlideSwipe](https://github.com/chestwood96/SlideSwipe) magnetic probe.

It uses a snap in frame clip to attach a servo that extends a bucket and brush over the build plate for the hotend nozzle to clean it of filament debris for cleaner prints.

Nozzle Wiper

Version 1 image:
Nozzle Wiper

For up to date modifications, check my [git repo](https://github.com/waytotheweb/voron/).

## Features:

- Servo used to extend system over the print bed
- Bucket and brush to clean nozzle
- Snap in frame clip that attaches to the left Y extrusion
- Klipper macros to control the entire process

## Printing:

- Use the Voron defaults and print in ABS or better
- The parts are orientated correctly in the STLs

## BOM:

- 1x Micro Servo 9G Servo Motor (SG90 or MG90 - mounts are provided for both)
- 6x M3x4x5mm Heat inserts
- 8x M3x8mm BHCS (2 for servo joint, 2 for carrier joint, 2 for frame mount, 2 for servo mount)
- 1x M3x10mm BHCS (for frame mount)
- 1x M3 nut (for frame mount)
- 1x Nozzle cleaning brush in Copper
- 3x OD 4mm, length 16mm, PTFE tube
- 1x OD 4mm, length 7mm, PTFE tube

## Hardware:

Brush:
https://www.amazon.co.uk/gp/product/B08H8SXBKM
https://www.aliexpress.com/item/4000801101276.html

Servo:
https://www.amazon.co.uk/gp/product/B0972M7JN1
https://www.aliexpress.com/item/1005001956791642.html

## Assembly:

startparts

Take the servo and attach a single arm to the top. Slowly and gently rotate the rotor clockwise until it hits its limit. Remove the arm and replace it on the servo so that it is positioned slightly more than 90 degrees clockwise as shown in the picture above.

This sets the servo arm to its 0 position. Use the smallest screw in the servo packaging to affix the arm to the servo in that position.

Place the 6 heat inserts as shown:

heatinserts

Remove the support tabs from the bucket. There is also a small support tap at the corner of the frame mount (see image at the bottom)

Cut down the brush head so that it matches the internal width of the brush holder. It's soft plastic so can be cut with a craft knife or a pair of angle cutters.

brush

Cut the PTFE tube into 3 lots of 16mm and 1 lot of 7mm. These will act as the hinges.

Push the cable connector through the slot provided in the servo mount as this will run on the inside of the extrusion. Fit the servo into the mount and fix in place with 2 M3x8mm screws. Don't overtighten:

mountservo

Place 1 of the 16mm piece and the 7mm piece of PTFE tubing into the servo arm. Pace 2 of the 16mm pieces of PTFE tubing into the parallel arm

insertptfe

This is a little fiddly: Position the servo arm with the short tube over the servo arm and the parallel arm next to it:

mountarms

Then screw in the servo joint using 2 M3x8mm screws. Do not tighten too much or the arm on the servo will bind (clicking noise). Make sure the arms rotate freely:

servojoint

Fit the carrier joint to the ends of the arms:

carrierjoint

Attach the tool carrier to the carrier joint using 2 M3x8mm screws:

toolcarrier

Attach the bucket to the tool carrier and make sure it goes on and comes off freely. If there's any stiffness, sand the bucket mounts on the tool carrier gently:

bucket

Place the M3x10mm screw through into the frame mount and wind on the nut about 2mm:

mountnut

Attach the frame mount to the servo mount using 2 M3x8mm screws through the groove. Do not tighten these screws, the servo mount should slide up and down the frame mount for now:

complete

Fit the brush head into the tool carrier.

Slowly and carefully, manually extend and straighten the arm to ensure a full range of motion:

Nozzle Wiper

Before permanently mounting the nozzle wiper to the printer test whether it works as expected by wiring the servo to the MCU from outside of the printer.

- Red wire    = +5v
- Brown wire  = GND
- Orange wire = signal pin

There are various choices for connecting the servo to the MCU. Here will will refer to the BTT SKR Mini E3 V2.0.

Always turn off the printer before connecting or removing anything to or from the MCU.

The simplest is to connect to the Neopixel or E0-STOP connector if it is not in use as it provides all 3 required connections. Alternatively, a [Klipper Expander](https://github.com/timmit99/Klipper-Expander) can be used if there are no free pins.

Remember, do not fit the arm to the printer at this point.

Upload the nozzlewiper.cfg file to your klipper configuration directory on the raspberry pi. If using Mainsail you can do this in MACHINE > Upload File.

Now edit printer.cfg and add an include line to the Macro section of your configuration:

```[include nozzlewiper.cfg]```

Modify nozzlewiper.cfg "[servo wipeServo]" and set the correct pin that you attached the single wire for the servo to. For example, PA8 would be on the Neopixel, PC15 would be the E0-STOP.

Now power on the printer. Once it has fully booted, you should see a list of new macros available all prefixed with "NW". You may need to home the server first.

Holding the nozzle wiper firmly in the hand by the extrusion mount, run the "NW DEPLOY" macro. The arm should extend 90 degrees. Then run the "NW RETRACT" macro and the arm should move to an almost straight position. It will not be completely straight as this helps prevent the arm+bucket from hitting the printers side panel.

Shutdown the printer.

Fit the Nozzle Wiper under the left Y extrusion: Feed the cable up through the provided routing on the frame mount. Then angle the frame mount into into the groove on underside of the left Y extrusion and push firmly so it snaps into place. Slide the assembly until the end of the tool carrier/bucket is ~5mm from the back panel. Now screw the fitted M3x10mm on the frame mount into the extrusion. Don't overtighten, it only needs small amount of contact to hold the Nozzle Wiper in place

![printerfit](images/printerfit.jpg)

You can route the cable along the extrusion. The cable should just fit through into the electronics bay, but you will likely need to remove the DuPont connector by lifting the taps to free the pins. You can then push the cable through and wire it to your MCU.

Follow the steps in the nozzlewiper.cfg file to configure the nozzle wiper setup.

## v1 Changelog:

- 2022-05-04 First release
- 2022-07-11 Added STEP CAD
- 2022-07-25 Improved printability of STL parts

## v2 Release:

- Use heat inserts instead of screwing into plastic for most screws
- Larger purge bucket
- More compact design
- Support both SG90 and MG90 motors
- New mounting system to support v0.1 variants, such as the Tri-Zero
- Improved cable routing

## v2 Changelog:

- 2022-09-05 First release

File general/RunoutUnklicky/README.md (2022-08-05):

# Runout UnKlicky Sensor

The Runout UnKlicky Sensor is a filament runout sensor that can be used to pause a print if printing filament breaks, runs out or otherwise is no longer present in the sensor.

The design uses magnets as the switch, making it easy and cheap to source BOM components.

design

design

## Printing:

Components:

- 1x Pin.stl
- 1x Roller.stl
- 1x Base.stl (different options are available[*])
- 1x Top.stl (different options are available[*])

Printer:

- Use the Voron defaults and print in ABS or better
- The parts are orientated correctly in the STLs

### [*]Base and Top:

There are 3 bases and 4 tops to choose from:

Bases:

- Base.stl is the standard base with push in holes for the PTFE tubes
- Base_PC4-M6.stl which allows the use of PC4-M6 connectors for the PTFE tubes
- Base_Collet.stl which allows the use of [E3D M4 collets](https://e3d-online.com/products/embedded-bowden-collet-for-metal-1-75mm)

Tops:

- Top.stl is the standard top with no mounting options
- Top_2020.stl provides mounting to 2020 extrusions using a t-nut
- Top_1515.stl provides mounting to 1515 extrusions using an inserted nut
- Top_1515_NoNut** provides mounting to 1515 extrusions if you have no inserted nuts available

[**] The Top_1515_NoNut can be used if you don't have any free nuts. It snaps into the extrusion. If it moves or slips, you can use a M2x10mm self-tapping screw to secure the sensor to the extrusion. Do note that the screw can scratch the inside the extrusion if that might bother you.

## BOM:

- 5x M3x8mm SHCS/BHCS (2x for the wired screws, 2x for the top/base, 1x for 2020 extrusion mount)
- 2x 6x3mm neodymium magnets (for the switch)
- 1x M2x10mm (optional for 1515 extrusion mount)
- 1x M3 Hammer T-Nut (for 2020 extrusion mount)
- 2x fork connectors (optional - for attaching wires)

## Assembly:

Parts used:
parts

Insert one of the magnets into the pin, push it in fully so that it shows in the groove gap:
pin

Insert the corresponding pin into the base and make sure that they attract from the outside as shown:
magnets

Insert the pin into the base with the pin grooves to the sides for the screws to enter. The pin should be pushed down to the bottom by the magnet in the base. Push the pin right up to the base magnet and screw in the screws to either side of the pin:
assembly

Place the top on the base and secure with two screws:
top

Attach cables to each screw that goes into the pin. There is no polarity and no voltage so it doesn't matter how they are connected. I used fork connectors for ease of use. Make sure the pin screws are screwed in tightly:
cable

Hook up the wires to a multimeter and put it on it's continuity test. It should show resistance (and/or beep) when there's no filament in the sensor:
nofilament

It should show no resistance (and/or remain silent) if you fully insert some filament into the sensor. Feed the filament through a few times from each side to ensure that you do not see any resistance when filament is present, and that you do see resistance when there is none:
filament

## Wiring:

Wire to an end-stop or similar pin. Do _not_ connect to voltage, _only_ to pin and GND. For example, with the BTT SKR MINI V2.0 you could use the E-STOP pin (PC15) and GND. For the BTT SKR Pico you could also use the E-STOP pin (gpio16) and GND.

## Klipper:

A simple configuration is available in this repo. Upload and include runoutunklicky.cfg in your printer.cfg and change the PIN definition to the one you chose on your MCU. The config file contains what is required to use a runout sensor, but it will only literally pause the machine and resume when prompted. To have the toolhead parked away from the print to an accessible place to change filament, implement one of the following examples in your klipper configuration:

- [AndrewEllis93](https://github.com/AndrewEllis93/Print-Tuning-Guide/blob/main/articles/useful_macros.md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)
- [Mainsail](https://docs.mainsail.xyz/configuration#pause-resume-cancel)

Test by inserting and removing filament. If it shows incorrectly in klipper add a ! in front of the PIN definition and test again.

## Credits:

Thanks to:

- [chestwood96](https://github.com/chestwood96) for inspiration from the UnKlicky probe for [SlideSwipe](https://github.com/chestwood96/SlideSwipe)
- [majarspeed](https://github.com/majarspeed/Unklicky) for the Unklicky probe
- [jlsa1](https://github.com/jlas1/Klicky-Probe/tree/main/Probes) for the Klicky and Unklicky probes
- [al3ph](https://github.com/VoronDesign/VoronUsers/tree/master/printer_mods/al3ph/filament_runout) for the "spinner" concept

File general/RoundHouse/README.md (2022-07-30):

# RoundHouse Direct Extruder

The RoundHouse is a direct drive extruder designed for the Voron v0.1

It uses the mounts from the [Mini-AfterSherpa](https://github.com/KurioHonoo/Mini-AfterSherpa) and was designed to complement the [5015 Toolhead](https://github.com/waytotheweb/voron/tree/main/V0/5015_Toolhead) toolhead. It can be used on any toolhead that uses the [Mini-AfterSherpa](https://github.com/KurioHonoo/Mini-AfterSherpa) design.

roundhousemount

rear

Please Note: This is a Work In Progress and things will likely change as issues are fixed and enhancements are made.

## Printing:

- Use the Voron defaults and print in ABS or better
- The parts are orientated correctly in the STLs

## BOM:

- 4x M3x6 or 8mm SHCS/BHCS (for securing the front to the back of the extruder)
- 1x M3x25mm  SHCS/BHCS (for the lever pivot)
- 5x Brass heat inserts (4 for the mount, 1 for the lever)
- 1x BMG Extruder Kit 
- 1x NEMA14 36mm pancake Motor with 10 tooth gear
- 1x ECAS04 Embedded Collet (optional)

## Sources:

- BMG Extruder Kit, e.g. [AliExpress](https://www.aliexpress.com/item/4000021186440.html) or direct from Bondtech
- NEMA14 36mm pancake Motor with 10 tooth gear, e.g. [AliExpress](https://www.aliexpress.com/item/1005003056906725.html)
- ECAS04 Embedded Collet, e.g. [Aliexpress](https://www.aliexpress.com/item/1005002538357279.html)

## CAD:

Will be published once released from WIP.

## Assembly:

Instructions to follow...

parts

lever

maingear

rear

roundhouse

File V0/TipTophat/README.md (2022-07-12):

# TipTophat

TipTophat is an alternative Tophat for the Voron v0.1 which uses the BOM panels. It provides 30mm in additional height as well as better access via the additional door. It places the side panels fully virtically to make the tophat square. It also comes with hinges that can be used with the [Tophat hinge  mod](https://github.com/VoronDesign/VoronUsers/tree/master/printer_mods/MSiemons/TophatHingeV0.1).

For the bleeding edge releases, see [my development repo](https://github.com/waytotheweb/voron)

tophatside

tophatopen

tophatclosed

## Printing:

- Use the Voron defaults and print in ABS. I have successfully printed the main body part(s) using 0.5mm layer width and 0.25mm layer height with 25% infill. This reduces both the time to print and the amount of filament used
- The parts are orientated correctly in the STLs
- If using the rear hing, print the appropriate Hinge_panel_left and Hinge_panel_right from [Tophat hinge  mod](https://github.com/VoronDesign/VoronUsers/tree/master/printer_mods/MSiemons/TophatHingeV0.1)

There is the choice of printing the whole body using the Unibody if you have a printer with a print bed of at least 238x238mm. Otherwise, you can print the separate quarters on a printer with at least 119x119mm printer bed. So they can be printed on a Voron v0, but it will be tight!

## BOM:

- Original BOM panels (panels of 2.5mm and 3.0mm have been tested)
- 28x M3x8mm** SHCS/BHCS (2x door frame hinge, 4x rear hinge (optional), 18x panel connectors, 4x tophat pins (optional))
- 1x M3x12mm SHCS/BHCS (door hinge)
- 1x M3x25mm SHCS/BHCS (door hinge)
- 28x Brass heat inserts (2x door frame hinge, 4x rear hinge (optional), 18x panel connectors, 4x tophat pins (optional))
- 2x 6x3mm Neodymium magnets
- VHB tape

** If your panels are 3mm in depth you will need to substitute 4x M3x8mm screws for 4x M3x(10 or 12)mm screws for the four mid connectors

## Assembly:

Note: These instructions use directions based on the tophat in front of you being upside down with the back facing away from you and the front in front of you. Once you place the tophat on the printer, instruction directions are as you look at the printer from the front.

### Building the frame and inserting the panels:

Place brass heat inserts into all the holes you are going to use. This is likely to be everything apart from the top 4 holes. Those top 4 holes are if you use the stock style pins to locate the tophat on the printer instead of using hinges at the back.

heatinserts

If you are building using the unibody instead of the four quadrants, you need to arrange the four quadrants with Q1 at the back left, Q2 back right, Q3 front left, Q4 front right. They need to be aligned correctly.

Place the top panel into the center of the bed and attach four connectors being very careful not to overtighten them, otherwise you can easily crack the print or the panels. It's better to have the connectors loose initially and tighten slightly until the panel doesn't move.

toppanelclips

Now work from the left, to the back, to the right, using the side and bottom connectors for each panel.

sidepanelclips

### Building the door:

The door connector takes a single 6x3mm Neodymium magnet. You should be able to press fit the magnet into the hole. If it's too loose, use a bit of superglue. If it's too tight, use a file  of drill bit to widen it a little. Attach this to the frame.

framemagnet

Take the two door hinge parts and assemble. The screws go into plastic, so do not tighten. The hinges should be a little bit loose so that it moves cleanly without binding. This can be adjusted later.

doorhinge

Put VHB tape on the panel hinge.

doorhingevhb

With the hinge open, put the panel into place abutting the panel into the hinge and centered. Press the panel to the hinge with some pressure to ensure a good seal.

doorpanel

Screw the hinge to the side of the tophat frame. There is adjustment available here for later if there are issues with the door opening/closing or being askew.

doorhingemount

doorhingefit

If you are going to use the hinged tophat, screw the hinge parts to the back of the tophat frame. You should also fit the hinge parts to the printer.

If you are using the standard locator pins, screw those in.

Put the tophat onto the printer and screw the rear hinges together if you are using them. Note: The hinge holes are deliberately oversized to allow for different tolerances and spacing for the tophat to sit well on the printer.

### Hanging the door:

Open the tophat door and close the main printer door. Now close the tophat door and check that it does not hit the main door. If it does there are a few adjustments that can be made later:

tophatdoor

### Adding the handle:

Take the door handle and the second magnet. With the tophat door closed, put the magnet against the frame magnet to get the correct orientation (use a marker pen on the magnet if it helps).

doormagnet

Maintaining the correct orientation place the magnet into one of the holes in the foot of the handle:

doorhandlemagnet

Place VHB tape over both of the handles feet:

doorhandlevhb

With the tophat door closed, align the handle with the magnet at the top opposite the magnet in the frame and keeping the handle straight press it onto the door. If it's not quite right, it should be fairly easy to carefully, and slowly, remove the handle and do it again.

doorhandlefit

You can adjust the frame mount from the inside screws to change the fitting of the hinge. You can also tighten and loosen the hinge screws to lower and raise the door panel. If none of that works, unscrew the door hinge and take the hinge+tophat door off. You can usually remove the hinge from the door, by very slowly pulling the hinge from the door panel, being careful not to snap the hinge or crack the panel. You can then redo the hanging steps for a better fit.

## Changelog:

- 2022-07-22 Updated Body Quarters and STEP file

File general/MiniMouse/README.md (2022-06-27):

# MiniMouse Direct Extruder

The MiniMouse is a direct drive extruder designed for the Voron v0.1

It uses the mounts from the [Mini-AfterSherpa](https://github.com/KurioHonoo/Mini-AfterSherpa) and works with both of my toolheads: [Dragon Burner](https://github.com/waytotheweb/voron/tree/main/V0/Dragon_Burner) and [5015 Toolhead](https://github.com/waytotheweb/voron/tree/main/V0/5015_Toolhead)

minimousemount

rear

Please Note: This is a Work In Progress and things will likely change as issues are fixed and enhancements are made.

## Printing:

- Use the Voron defaults and print in ABS or better
- The parts are orientated correctly in the STLs

## BOM:

- 4x M3x6 or 8mm SHCS/BHCS (for securing the front to the back of the extruder)
- 1x M3x25mm  SHCS/BHCS (for the lever pivot)
- 5x Brass heat inserts (4 for the mount, 1 for the lever)
- 1x BMG Extruder Kit 
- 1x NEMA14 36mm pancake Motor with 10 tooth gear
- 1x ECAS04 Embedded Collet (optional)

## Sources:

- BMG Extruder Kit [AliExpress](https://www.aliexpress.com/item/4000021186440.html)
- NEMA14 36mm pancake Motor with 10 tooth gear [AliExpress](https://www.aliexpress.com/item/1005003056906725.html)
- ECAS04 Embedded Collet [Aliexpress](https://www.aliexpress.com/item/1005002538357279.html)

## CAD:

Will be published once released from WIP.

## Assembly:

parts

lever

leverfit

maingear

rear

minimouse

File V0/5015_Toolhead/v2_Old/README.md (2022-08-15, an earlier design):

# 5015 Toolhead v3 (The Mailbox)
This is a Voron V0.1 toolhead that uses the guts of a 5015 fan for part cooling and incorporates Neopixel RGBW leds. It currently works with the LGX Lite extruder, the [Voron PocketWatch 2](https://github.com/VoronDesign/Pocket-Watch) and the [RoundHouse](https://github.com/waytotheweb/voron/tree/main/general/RoundHouse) extruder designed specifically for this hotend.

It uses the standard Voron V0.1 X carriage (and the MGN9C mod X carriage), is inspired by the [Mini-AfterSherpa](https://github.com/KurioHonoo/Mini-AfterSherpa).

This toolhead should not normally lose any X, Y or Z travel.

5015_Toolhead
v2
airflow

## Printing:

- Use the Voron defaults and print in ABS or better
- The parts are orientated correctly in the STLs
- The cowl will have different variants for choice of probe, or no probe
- Choose the mount for the specific hotend to be used
- If using the [Voron Pocket-Watch 2](https://github.com/VoronDesign/Pocket-Watch) extruder, print the source STL's from the repository, but use the [Guts_p2_x1.stl ](STLs/Guts_p2_x1.stl) from this project instead. The Pocket-Watch is [inverted for this toolhead](images/PocketWatch2.jpg). (Note: The PTFE tube will likely pop out of the top of extruder when fully unloading filament as there is no room for the tube retainer)

## BOM:

- 4x M3x35mm SHCS/BHCS (2 for the hotend mount, 2 for the X carriage mount)
- 2x M3x20mm  SHCS/BHCS (for the extruder mount)
- 2(4)x Brass heat inserts (2 for cowl hotend mount, 2 optional for ADXL mount)
- 1x 5015 part cooling fan that you are happy to cut to pieces
- 1x 3010 hotend fan (24v recommended)
- 2x Neopixels and wiring (optional)

The cowl variants support a no probe setup, [SlideSwipe magnetic probe](https://github.com/chestwood96/SlideSwipe), [ZeroClick probe](https://github.com/zruncho3d/ZeroClick), [(Un)Klicky Probe](https://github.com/jlas1/Klicky-Probe) and a MiniSlideSwipe using the SlideSwipe mechanism

## Supported Hotends:

- Revo Voron
- Dragon SF/HF
- DragonFly
- Rapido HF

## Fans:

I am using these fans:

- 24v Blower 5015: [Mellow (Pengda)](https://www.aliexpress.com/item/32844339310.html)
- 24v Axial 3010: [Gdstime](https://www.aliexpress.com/item/1005002857100082.html)

## Heatsink Thermistor:

Each cowl includes a hole at the top to insert a thermistor. With this in place, klipper can track the temperature of the heatsink to watch for heat creep from the heatbreak. You can have klipper abort and shutdown before your whole toolhead melts! You only need a simple klipper entry for the appropriate pin on your MCU, e.g.:

```
[temperature_sensor Heatsink]
sensor_type: Generic 3950
sensor_pin: expander:PA5
max_temp: 85
```

Klipper will shutdown if the top of the heatsink hits 85C. You can use thermal paste to help keep a bulb thermistor in contact with the heatsink and lay the wires through the provided groove, then fitted the extruder on top to hold it in place.

## Assembly:

startparts

Place brass inserts into the cowl for mounting the hotend and the adxl mount if using this.

Remove the fan duct supports carefully. Check that none of the removed plastic has fallen into the ducts:
supports

The 3010 hotend fan is meant to be press fit. If it's too tight, sand or file the opening but don't force it in otherwise it can deform and the blades will hit the casing. If it's too lose or rattles, use M3 screws to secure it through the top two holes into the cowl. Routing of the fans cables are through the channel provided:
hotendfan

You need to remove most of the outer shell of the 5015 fan. Before doing so, please connect the fan to your MCU/toolhead board and ensure that it responds to pmw from klipper.

You need to split the 5015 fan casing in half by poking the tabs on the fan. Once done, take the half with the fan attached and carefully trim off the casing up to the fins. I use side cutters, but a craft knife should work. If more breaks off it shouldn't be a problem. What you want to be left with is a ~35mm circle of casing that matches the diameter of the actual fan. Be very careful not to cut the fan wires, or to manipulate the wires too much as they can easily break from their solder patches (a dab of hot glue helps):

fancut

Using VHB tape, cut to fit the back of the fan. You might want to remove any stickers on the back of the fan casing to ensure a good bond:

fantape

Affix the fan to the fan cap by threading the wires through the hole and centre the fan into the middle of the fan cap. It does not need to be 100% central, but the closer the better it will look:

fancap

Fit the fan cap onto the cowl and ensure that it sits well without rubbing on the cowl:

fanmount

The fan cover is a light friction fit and is held in place by the extruder mount:

fanfit

If you are going to use Neopixels, remove the two tabs at the inner base of the cowl to expose the Neopixel holes:

rgbwtabs

Route the Neopixel cable through the provided groove and align with the hole:

rgbwcable

Place the Neopixel diffuser/holder over the top of the Neopixel with the longer sides facing down and the front:

rgbwdiffuser

Push the diffuser/holder into the whole being careful not to dislodge the Neopixel being careful not to leave the cables pinched:

rgbwfit

Affix your chosen hotend mount to your hotend. This must be done before mounting to the X carriage as the screws to the hotend will no longer be accessible:

hotendmount

Affix the extruder mount to the bottom of the extruder:

extrudermount

Mount the extruder on top of the hotend onto the cowl using 2 M3x20 screws to check the assembly:

testassembly

Remove the extruder and hotend from the cowl. Attach the hotend assembly to the X carriage using 3 M3x20mm screws.

Offer up the cowl and extruder assembly to the hotend mount and secure using 2 M3x20mm screws. Be careful not to catch any wires between the surfaces (this step needs a bit of juggling to get everything to align and fit and the wires to route correctly):

xmount

Zip-tie the wires to the back of the assembly.

Plugin, test the fans and redo your X offset as it will probably have changed slightly.

## Neopixels:

Make sure the cables interconnecting the two Neopixels is long enough to loop up both sides of the cowl and above the extruder mount at the rear:
rgbwwiring

For creating the actual wiring, refer to page 46 of the [StealthBurner manual](https://github.com/VoronDesign/Voron-Stealthburner/blob/main/Manual/Assembly_Manual_SB.pdf)

To configure the Neopixels in Klipper, I'd suggest using the [StealthBurner config file](https://github.com/VoronDesign/Voron-Stealthburner/blob/main/Firmware/stealthburner_leds.cfg) and change the following to assign the two Neopixels a wider range of colour options:

```
variable_logo_idx:              "1,2"
variable_nozzle_idx:            "3" # not used
```

## v1 Changelog:

- 2022-06-03 WIP release
- 2022-06-04 Added support for the Voron PocketWatch 2 extruder
- 2022-06-05 Added cable exit hole in Klicky cowl
- 2022-06-05 Added cable ducts to all cowls
- 2022-06-05 Moved zip-ties from cowls to hotend mounts
- 2022-06-07 Added Neopixel support
- 2022-06-08 Updated all STLs, images and docs
- 2022-06-11 Updated the assembly instructions
- 2022-06-13 Fixed the Revo Voron mount
- 2022-06-13 Added Rapido HF mount with no loss in Z
- 2022-07-03 Added ZeroClick support

## New version 2:

- Moved to Fusion 360
- Increased and improved airflow
- Improved heat warping protection around RGBW ducts
- Improved cable routing
- Improved RapidoHF support
- Improved hotend fan push fit
- Improved RGBW logo lighting
- Improved RGBW installation and wiring instructions
- 2 screw X carriage support (3rd screw was unnecessary)

## v2 Changelog:

- 2022-07-30 Version 2 release
- 2022-07-30 RoundHouse extruder release

## New version 3:

- Improved easy mounting using front screws
- Improved size with an reclaimed 1mm on the Y axis (it all counts!)
- Improved cable routing
- Improved RapidoHF support
- Improved fan cover
- Improved airflow using CFD for the part cooling ducts
- Improved RGBW install and routing
- New MiniSlideSwipe probe (for use with SlideSwipe)
- Improved ZeroClick support
- Improved heatbreak temperature sensor routing
- Improved built-in supports

## v3 Changelog:

- 2022-08-15 Version 3 release

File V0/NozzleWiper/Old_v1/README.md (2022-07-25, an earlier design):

# Nozzle Wiper
This is a nozzle purge and wipe mod for the Voron V0.1. It is based on the [SlideSwipe](https://github.com/chestwood96/SlideSwipe) magnetic probe by [chestwood96](https://github.com/chestwood96).

It uses a snap in frame clip, that doesn't require screws, to attach a servo
that extends a bucket and brush over the build plate for the hotend nozzle to
clean it of filament debris for cleaner prints.

Nozzle Wiper

## Goals:

- Servo used to extend system over the print bed
- Bucket and brush to clean nozzle
- Snap in frame clip that does not need screws
- Klipper macros to control the entire process

These have all been implemented in this public release.

## Printing:

- Use the Voron defaults and print in ABS or better
- The parts are orientated correctly in the STLs
- There is a single All In One STL that fits onto the v0.1 build plate to make life easier

## BOM:

- 1x Micro Servo 9G Servo Motor (SG90/MG90)
- 2x M3x8mm BHCS (for servo mount)
- 2x M3x6mm BHCS (for brush holder mount)
- 2x M2x10mm self tapping screws (optional: for snap in frame clip)
- 1x Nozzle cleaning brush in Copper
- 3x OD 4mm, length 16mm, PTFE tube
- 1x OD 4mm, length 7mm, PTFE tube

## Hardware:

Brush:
https://www.amazon.co.uk/gp/product/B08H8SXBKM
https://www.aliexpress.com/item/4000801101276.html

Servo:
https://www.amazon.co.uk/gp/product/B0972M7JN1
https://www.aliexpress.com/item/1005001956791642.html

## Assembly:

parts

### Step 1 - Set Servo

parts

Take the servo and attach a single arm to the top. Slowly and gently rotate the rotor clockwise until it hits its limit. Remove the arm and replace it on the servo so that it is positioned slightly more than 90 degrees clockwise as shown in the picture above.

This sets the servo arm to its 0 position. Use the smallest screw in the servo packaging to affix the arm to the servo in that position.

### Step 2 - Parts Preparation

bucket

Remove the support tabs from the bucket.

brush

Cut down the brush head so that it matches the internal width of the brush holder. It's soft plastic so can be cut with a craft knife or a pair of angle cutters.

Cut the PTFE tube into 3 lots of 16mm and 1 lot of 7mm. These will act as the hinges.

### Step 3 - Fit Servo to Mount

servo

Push the cable connector through the slot provided in the servo mount as this will run on the inside of the extrusion. Fit the servo into the mount and fix in place with 2 M3x8mm screws. You may need to fettle the plastic around the hole for the top of the servo for it to fit. Note the correct orientation of the servo.

### Step 4 - Servo Section Assembly

assembly

Place 1 of the 16mm pieces and the 7mm piece of PTFE tubing into the sections as shown above. Place the section with the space for the servo arm first and then the double ended section behind it. Carefully seat the PTFE tubes into the servo mount and fix in place with the angled part shown to the top of the mount:

assembly

### Step 5 - Brush Section Assembly

parts

Place the remaining pieces of 16mm PTFE tubing into the ends of the fitted sections and then fix onto the brush holder using the remaining 2 M3x6mm screws.

completed

Fit the brush head into the brush holder:

brushholder

### Step 6 - Motion

Slowly and carefully, manually extend and straighten the arm to ensure a full range of motion:

motion

### Step 7 - Wiring

Before permanently mounting the nozzle wiper to the printer test whether it works as expected by wiring the servo to the MCU from outside of the printer.

- Red wire    = +5v
- Brown wire  = GND
- Orange wire = signal pin

There are various choices for connecting the servo to the MCU. Here will will refer to the BTT SKR Mini E3 V2.0.

Always turn off the printer before connecting or removing anything to or from the MCU.

The simplest is to connect to the Neopixel or E0-STOP connector if it is not in use as it provides all 3 required connections. Alternatively, a [Klipper Expander](https://github.com/timmit99/Klipper-Expander) can be used if there are no free pins.

Remember, do not fit the arm to the printer at this point.

### Step 8 - Klipper

Upload the nozzlewiper.cfg file to your klipper configuration directory on the raspberry pi. If using Mainsail you can do this in MACHINE > Upload File.

Now edit printer.cfg and add an include line to the Macro section of your configuration:

```[include nozzlewiper.cfg]```

### Step 8 - Servo Testing

Modify nozzlewiper.cfg "[servo wipeServo]" and set the correct pin that you attached the single wire for the servo to. For example, PA8 would be on the Neopixel, PC15 would be the E0-STOP.

Now power on the printer. Once it has fully booted, you should see a list of new macros available all prefixed with "NW".

Holding the nozzle wiper firmly in the hand by the extrusion mount, run the "NW DEPLOY" macro. The arm should extend 90 degrees. Then run the "NW RETRACT" macro and the arm should move to an almost straight position. It will not be completely straight as this helps prevent the arm+bucket from hitting the printers side panel.

Shutdown the printer.

### Step 9 - Installation and Wiring

![mounted](images/wireplacement.jpg)

Fit the Nozzle Wiper arm to the left extrusion. This uses a push fit method. Line the mount up with the logo side to the extrusion. Feed the cable up into the groove on the inner section of extrusion and push the logo side into the extrusion and the push the other side into the inner section of extrusion. It should snap into place. You should be just about able to move the arm up and down in the extrusion.

![mounted](images/mounted.jpg)

If it is too loose, there are two holes in the logo side of the mount where you can insert 2 x M2x10mm self tapping screws. Inserting the screws here will expand the mount inside the rail to hold it in place. If you then need to move the arm up and down you will have to remove the self tapping screws completely.

You can route the cable up the extrusion and along the bottom of the Y axis. The cable should just fit through into the electronics bay, but you will likely need to remove the DuPont connector by lifting the taps to free the pins. You can then push the cable through and wire it to your MCU.

### Step 10 - Klipper Configuration

Follow the steps in the nozzlewiper.cfg file to configure the nozzle wiper setup.

## Changelog:

- 2022-05-04 First release
- 2022-07-11 Added STEP CAD
- 2022-07-25 Improved printability of STL parts

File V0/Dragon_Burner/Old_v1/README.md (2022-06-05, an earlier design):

# Dragon Burner
This is my take on the Voron V0.1 toolhead. I wanted to improve the cooling of the Dragon HF hotend and provide improved part cooling when printing filament that needs it (e.g. PLA).

It uses the standard Voron X carriage, is based on the [Mini-AfterSherpa](https://github.com/KurioHonoo/Mini-AfterSherpa) and uses its extruder mounting system, but I've designed it from the ground up using TinkerCad :man_facepalming:

Dragon Burner

## Goals:

- Dragon SF and HF hotend support
- Dragonfly hotend support
- E3D Revo Voron hotend support
- Rapido HF hotend support
- Single 3010 24v hotend cooling fan
- Twin 4010 24v blower part cooling fans
- [SlideSwipe magnetic probe](https://github.com/chestwood96/SlideSwipe) support
- [(Un)Klicky Probe](https://github.com/jlas1/Klicky-Probe) support
- [ZeroClick probe] (https://github.com/zruncho3d/ZeroClick) support
- ADXL345 mount point and board mount
- Heatsink thermistor support
- Screwless hotend fan attachment

These have all been implemented in this public release.

## Printing:

- Use the Voron defaults and print in ABS or better. The part is orientated correctly in the STL.
- Print the appropriate cowl from the Toolheads directory
- Print the FanDuct_Left.stl and the appropriate FanDuct_Right_*.stl depending on whether you use a probe 

## BOM:

In addition to the [Mini-AfterSherpa](https://github.com/KurioHonoo/Mini-AfterSherpa):

- 2x M3x6mm SHCS/BHCS (for fan duct mounts)
- 4x M3 5x4mm additional heat inserts (2 for ADXL345 mount, 2 for fan duct mounts)
- 2x M3x16mm BHCS (optional: for hotend fan)
- 2x M3x8mm BHCS (for ADXL mount)[*]
- 2x M2x10mm self tapping screws (for blower fans)
- 2x M2x8mm BHCS and nuts (to mount ADXL)
- 2x 4010 blower fans (24v recommended)
- 1x 3010 hotend fan (24v recommended)

The cowl supports a no probe setup, [SlideSwipe magnetic probe](https://github.com/chestwood96/SlideSwipe), [(Un)Klicky Probe](https://github.com/jlas1/Klicky-Probe) and [ZeroClick probe](https://github.com/zruncho3d/ZeroClick)

## Fans:

I am using these fans:

- 24v Axial 3010: [Gdstime](https://www.aliexpress.com/item/1005002857100082.html)
- 24v Blower 4010: [Gdstime](https://www.aliexpress.com/item/32799324058.html)

## Heatsink Thermistor:

Each cowl includes a hole at the top to insert a thermistor. With this in place, klipper can track the temperature of the heatsink to watch for heat creep from the heatbreak. You can have klipper abort and shutdown before your whole toolhead melts! You only need a simple klipper entry for the appropriate pin on your MCU, e.g.:

```
[temperature_sensor Heatsink]
sensor_type: Generic 3950
sensor_pin: expander:PA5
max_temp: 85
```

Klipper will shutdown if the top of the heatsink hits 85C. You can use thermal paste to help keep a bulb thermistor in contact with the heatsink and layed the wires through the provided groove, then fitted the extruder on top to hold it in place.

## Assembly:

- Add fan duct inserts to the cowl being careful not to push them all the way through. They should fit level on both surfaces with the standard M3 5x4mm inserts
- Attach the fan ducts to the cowl using 2x M3x6mm. SHCS preferred for a low profile
- Remove the small duct overhang supports
- If you are using one of the Klicky variants, add the wires and magnets to the fan duct
- Add ADXL mount inserts to the lower outside left of the toolhead
- There is a hole on the left face to put the left 4010 blower fan cable through, do this before going further
- Insert the 3010 hotend fan and route both fan cables through the provided channel
- Secure the 3010 fan either using the fan nubs[*], or use 2 FHCS (the fan will need to be chamfered) or BHCS screws
- Take care when screwing the hotend fan as it's secured into plastic and too much force will strip the created threads and/or deform the fan
- Be careful not to leave the cables loose or over the hotend mount
- Insert the 4010 fans into each side and slide backwards into the restraints
- Secure each fan using a M2x10mm self tapping screw at the bottom front hole
- Carefully mount the hotend into place making sure not to pinch any fan cables
- Run the hotend and fan cables along the 10mm side of the 4010 fans on each side and zip tie at the top
- Fit the heatbreak thermistor if you are going to use one
- Fit your extruder
- Offer up to the toolhead mount and secure, being careful not to trap any of the cables
- Check the X and Y movement still triggers the end-stops and that none of the cables are causing the belts to bind to the x axis
- Check you have modified all the fan connections on the MCU if you have switched to higher voltage fans

[*] NOTE: You may lose 1-2mm on the Y axis when using BHCS screws. To reclaim most of that loss, instead use the fan nubs. These are inserted after placing the 3010 fan into the housing from the sides with the domes pointing inwards. The 4010 fans will then hold these in place. If you need to remove the 3010 fan, remove the 4010 fans first, then carefully screw in a short M3 screw into the holes in the centre of the nubs to extract. If either the 3010 fan does not have indents or if it rattles, then you will have to use 2 screws instead to secure the fan. You can use BHCS screws, or to regain some of the Y loss, use FHCS screws. You can then chamfer the insides of the top two fan screw holes to allow the FHCS screws to be flush against the fan and cowl.

## Changelog:

- 2022-04-12 First release
- 2022-04-12 Fixed issue with incorrect part placement
- 2022-04-13 Added mounts for the Dragonfly hotend
- 2022-04-13 Added mounts for the Rapido HF hotend
- 2022-04-13 Fixed clearance to socks on Rapido and Dragonfly
- 2022-04-16 Fixed misalignment of filament tube hole for Dragonfly
- 2022-04-16 New ducts improve airflow over nozzle
- 2022-04-19 New ducts improve airflow direction
- 2022-04-19 Added hole and wire groove for heatsink thermistor
- 2022-04-21 Added Klicky variant support
- 2022-04-21 Reorganised repo to separate hotends
- 2022-04-21 Added screwless 3010 hotend fan mount
- 2022-04-27 Added mounts for the E3D Revo Voron hotend
- 2022-05-07 Added wire exit for Klicky mount for all hotends
- 2022-05-08 Modified all toolheads to use removeable fan ducts
- 2022-05-10 Links to public Tinkercad added
- 2022-05-11 Updated Klicky fan ducts
- 2022-05-21 Added bridging supports to Klicky fan ducts
- 2022-06-03 Added ZeroClick variant support
- 2022-06-05 Easier to print fan ducts and magnet helper for ZeroClick

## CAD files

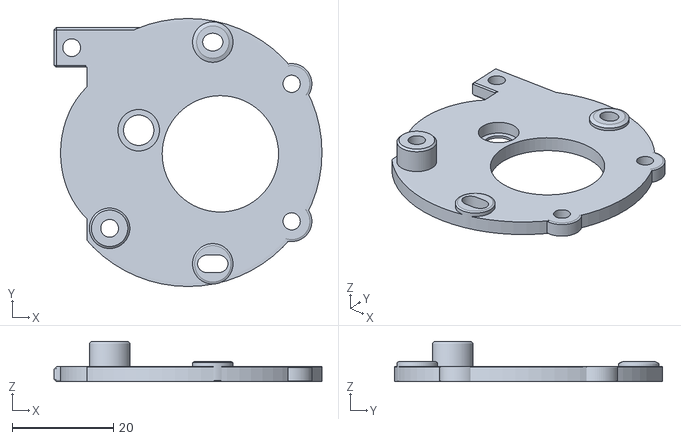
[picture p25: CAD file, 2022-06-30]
general/MiniMouse/STLs/MiniMouse_Back.stl
53.0 x 53.0 x 8.00

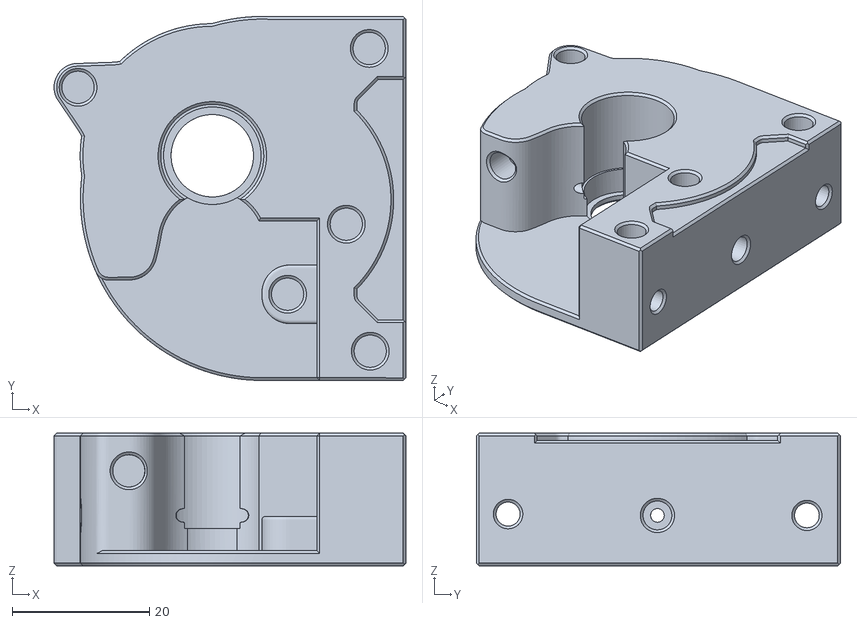
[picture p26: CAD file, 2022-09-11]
general/RoundAbout/STLs/Front.stl
51.2 x 53.0 x 19.3

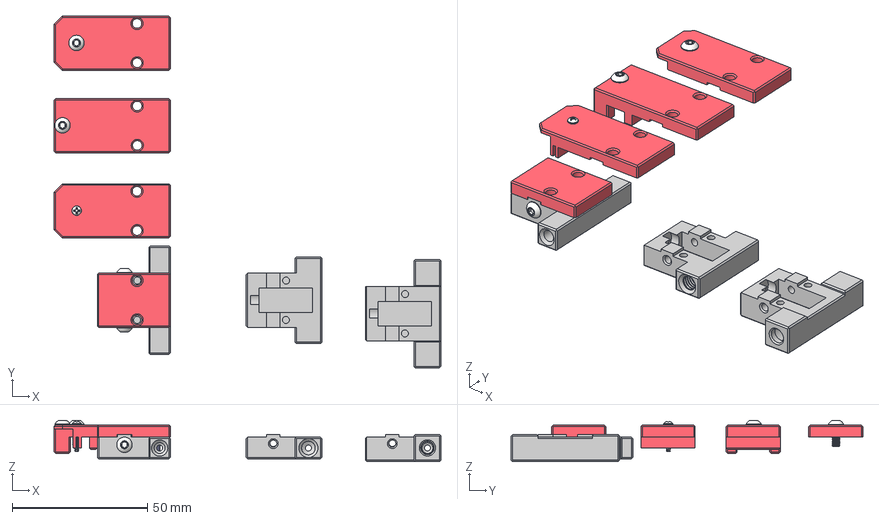
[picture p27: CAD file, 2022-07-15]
general/RunoutUnklicky/CAD/RunoutUnKlicky.step
143.1 x 130.0 x 15.2 mm
Pin
Top
94500A222_316 Stainless Steel Button Head Hex Drive Screws (2)
94500A222_316 Stainless Steel Button Head Hex Drive Screws (3)
Magnet (1)
Magnet (2)
Top_1515_NoNut
Top_2020 (1)
90380A328_Phillips Rounded Head Thread-Forming Screws (1)
94500A222_316 Stainless Steel Button Head Hex Drive Screws (1) (2)
94500A222_316 Stainless Steel Button Head Hex Drive Screws (1) (3)
Top_1515
Roller (1)
Base_PC4-M6
Base
Base_Collet

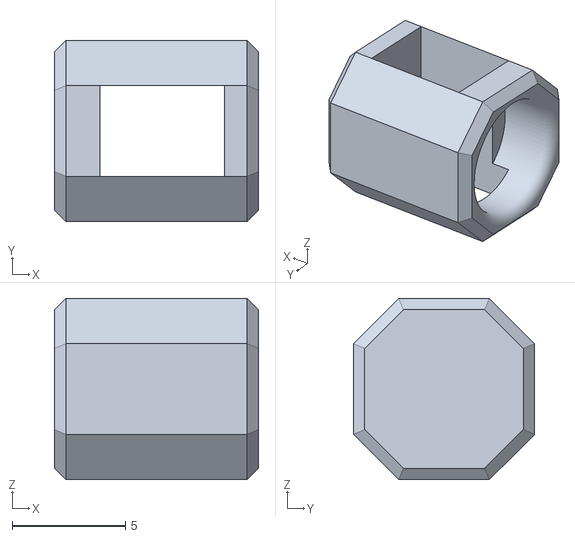
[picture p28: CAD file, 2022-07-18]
general/RunoutUnklicky/STLs/Pin.stl
9.00 x 8.00 x 8.00

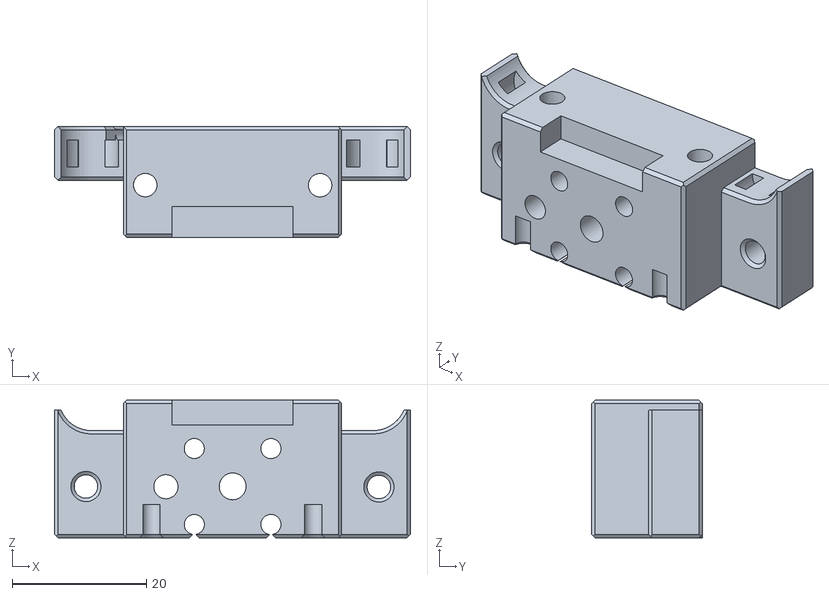
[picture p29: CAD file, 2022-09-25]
V0/5015_Toolhead/STLs/Dragon_mount.stl
53.0 x 16.5 x 20.5

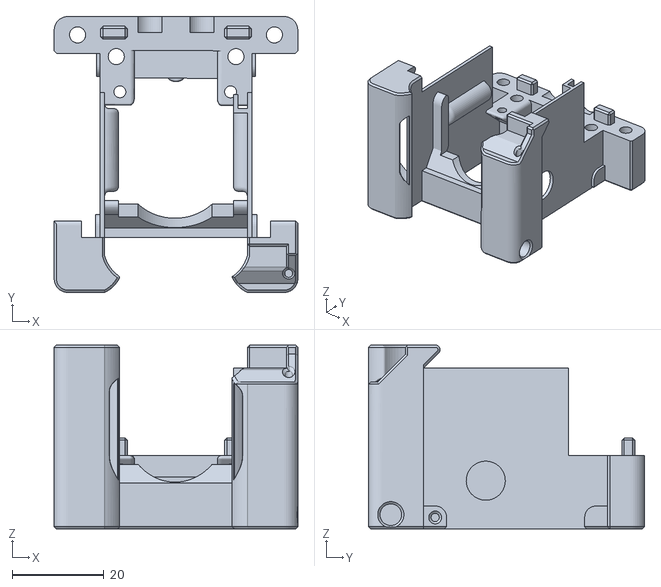
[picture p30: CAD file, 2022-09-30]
V0/Dragon_Burner/STLs/Cowl_ZeroClick.stl
53.0 x 60.0 x 40.0

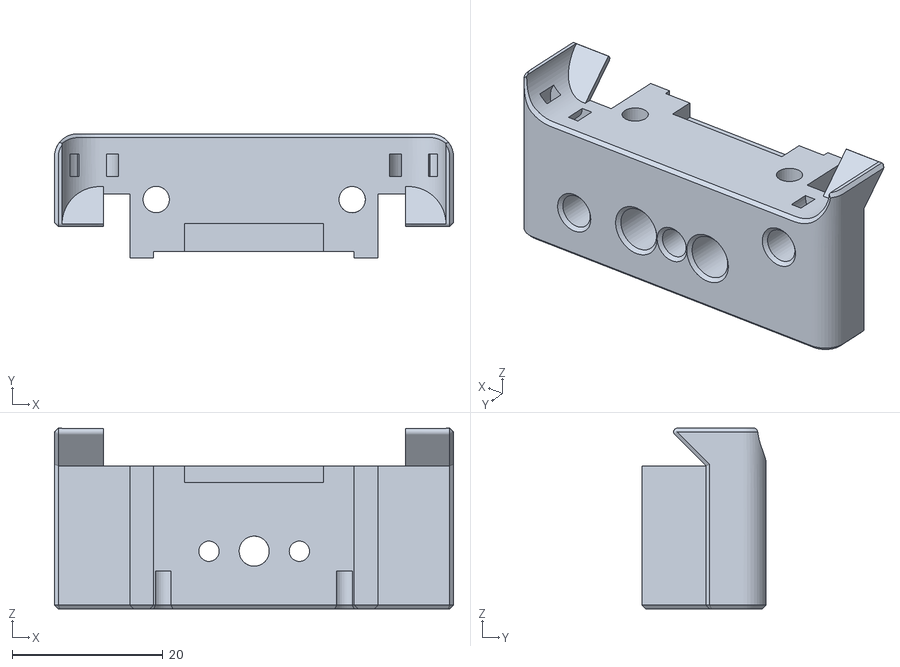
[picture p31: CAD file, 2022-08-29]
V0/Dragon_Burner/STLs/Orbiter1.5/NF_Crazy_Mount.stl
53.0 x 16.5 x 24.0

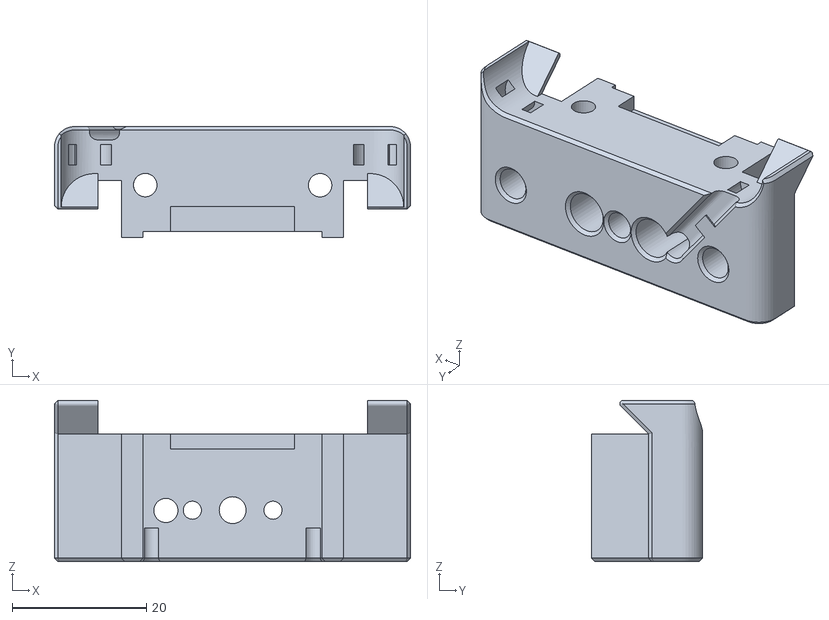
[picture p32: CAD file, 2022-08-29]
V0/Dragon_Burner/STLs/Orbiter2/NF_Crazy_Mount.stl
53.0 x 16.5 x 24.0

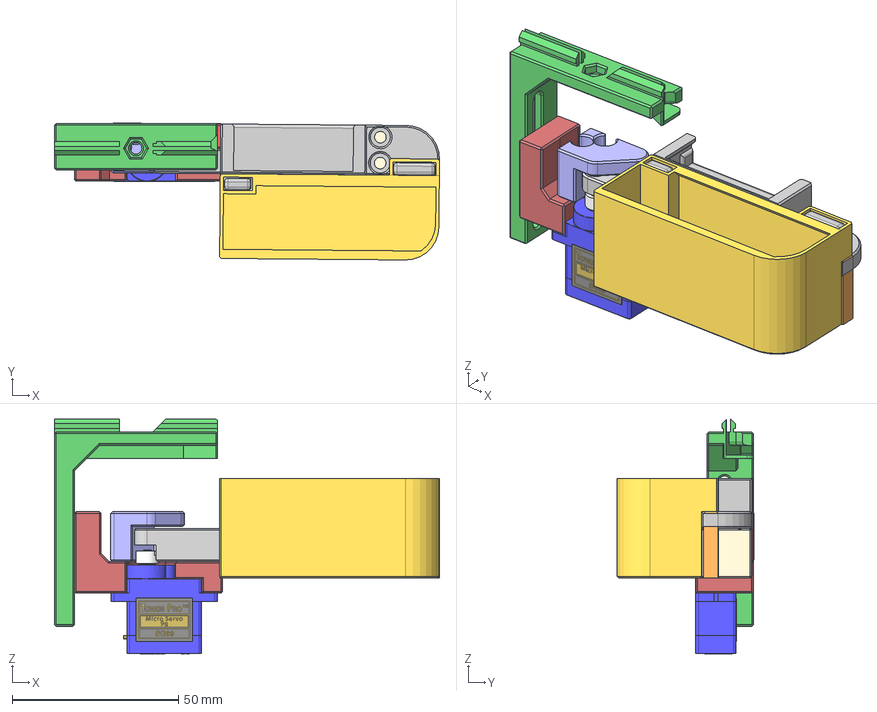
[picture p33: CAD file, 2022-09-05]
V0/NozzleWiper/CAD/NozzleWiper v2.step
116.0 x 41.3 x 70.7 mm
Servo_Arm
Parallel_Arm
RailMountSide (1)
RailMountTop (1)
ProbeCarrierBottom (1)
ProbeCarrierTop (1)
91290A111_NO THREADS_Alloy Steel Socket Head Screw (2) x 2
6x3 Magnet (1)
16mm 4x2 PTFE Tube (2) x 2
SG90 - Micro Servo 9g - Tower Pro.1_Pea
SG90 - Micro Servo 9g - Tower Pro.2_Pea
SG90 - Micro Servo 9g - Tower Pro.6_BS EN ISO 7045 - M2 x 4 - Z - 4S
Bucket
Frame_Mount
Servo_Mount_SG90
Tool_Carrier (1)
M3 Threaded Insert x 6

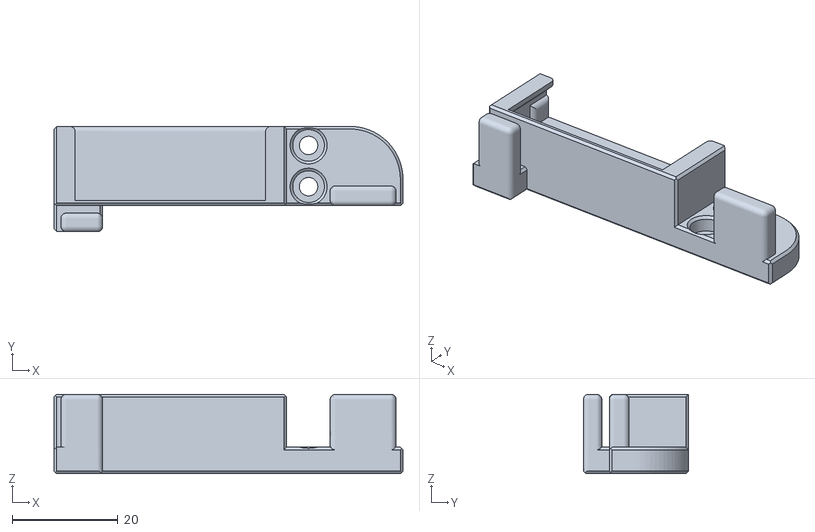
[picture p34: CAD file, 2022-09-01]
V0/NozzleWiper/STLs/Tool_Carrier.stl
66.0 x 19.9 x 15.0

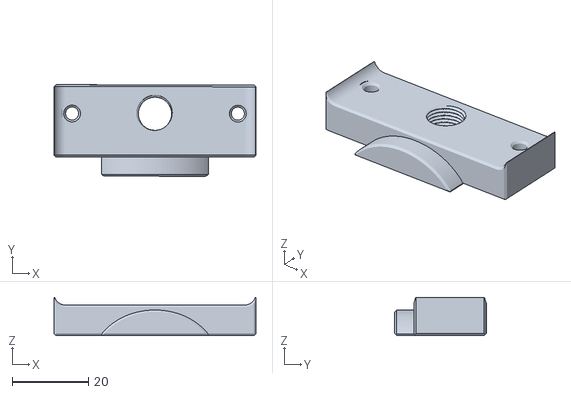
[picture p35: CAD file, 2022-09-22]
V0/Rapid_Burner/STLs/Bowden_Mount.stl
53.0 x 24.0 x 10.0

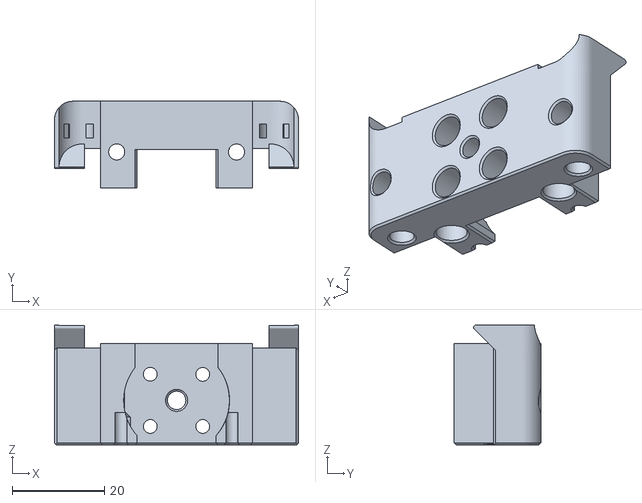
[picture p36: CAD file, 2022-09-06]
V0/Rapid_Burner/STLs/HF/Standard_Mount.stl
53.0 x 18.8 x 26.0

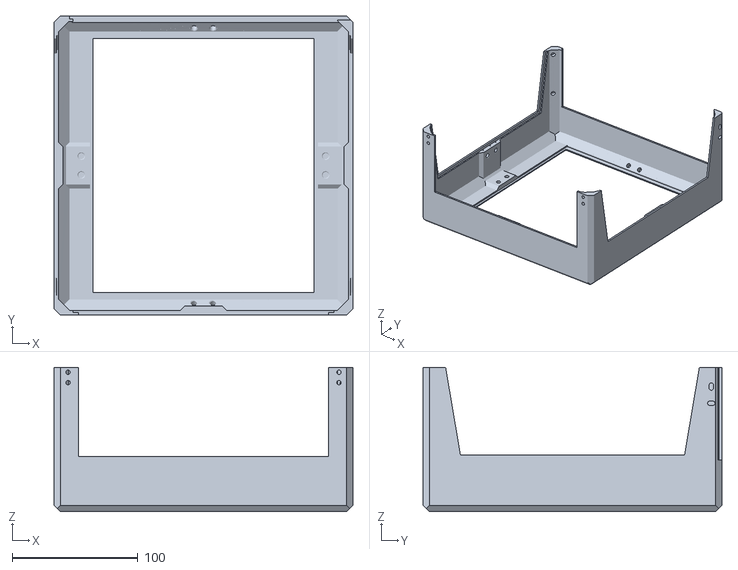
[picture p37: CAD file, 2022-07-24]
V0/TipTophat/STLs/Unibody.stl
238.0 x 238.0 x 115.0

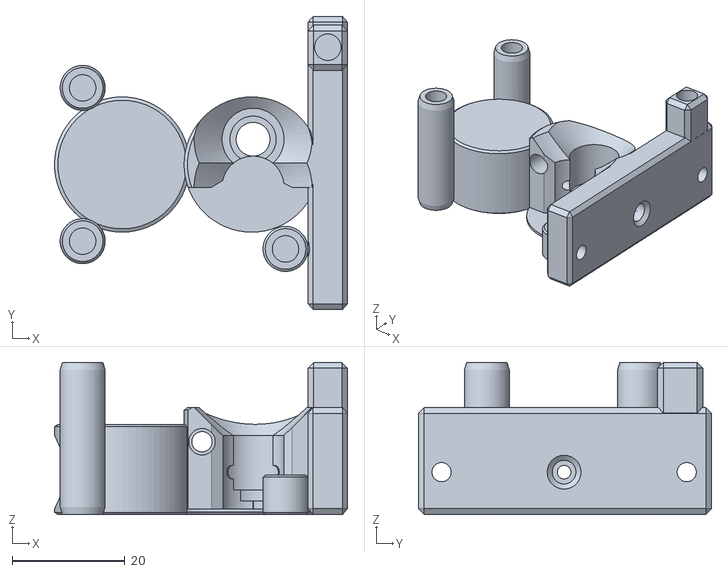
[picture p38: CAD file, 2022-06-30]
general/MiniMouse/STLs/MiniMouse_Front.stl
52.0 x 52.0 x 27.0

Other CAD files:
general/RoundAbout/STLs/Latch.stl
general/RunoutUnklicky/STLs/Roller.stl
V0/5015_Toolhead/STLs/Bowden_Mount.stl
V0/Dragon_Burner/STLs/Cowl_SlideSwipe.stl
V0/5015_Toolhead/STLs/Cowl_Klicky.stl
V0/5015_Toolhead/STLs/Cowl_MiniSlideSwipe.stl
V0/5015_Toolhead/STLs/Cowl_NoProbe.stl
V0/5015_Toolhead/STLs/Cowl_SlideSwipe.stl
V0/5015_Toolhead/STLs/Cowl_ZeroClick.stl
V0/5015_Toolhead/STLs/Dragonfly_mount.stl
V0/5015_Toolhead/STLs/Extruder_Mount.stl
V0/5015_Toolhead/STLs/Fan_Cover.stl
V0/5015_Toolhead/STLs/NF_Crazy_Mount.stl
V0/5015_Toolhead/STLs/RapidoHF_mount.stl
V0/5015_Toolhead/STLs/RevoVoron_Mount.stl
V0/5015_Toolhead/STLs/[c]_LED_Cover_Left.stl
V0/5015_Toolhead/STLs/[c]_LED_Cover_Right.stl
V0/5015_Toolhead/v2_Old/STLs/Cowl_Klicky.stl
V0/5015_Toolhead/v2_Old/STLs/Cowl_NoProbe.stl
V0/5015_Toolhead/v2_Old/STLs/Cowl_SlideSwipe.stl
V0/5015_Toolhead/v2_Old/STLs/Cowl_ZeroClick.stl
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

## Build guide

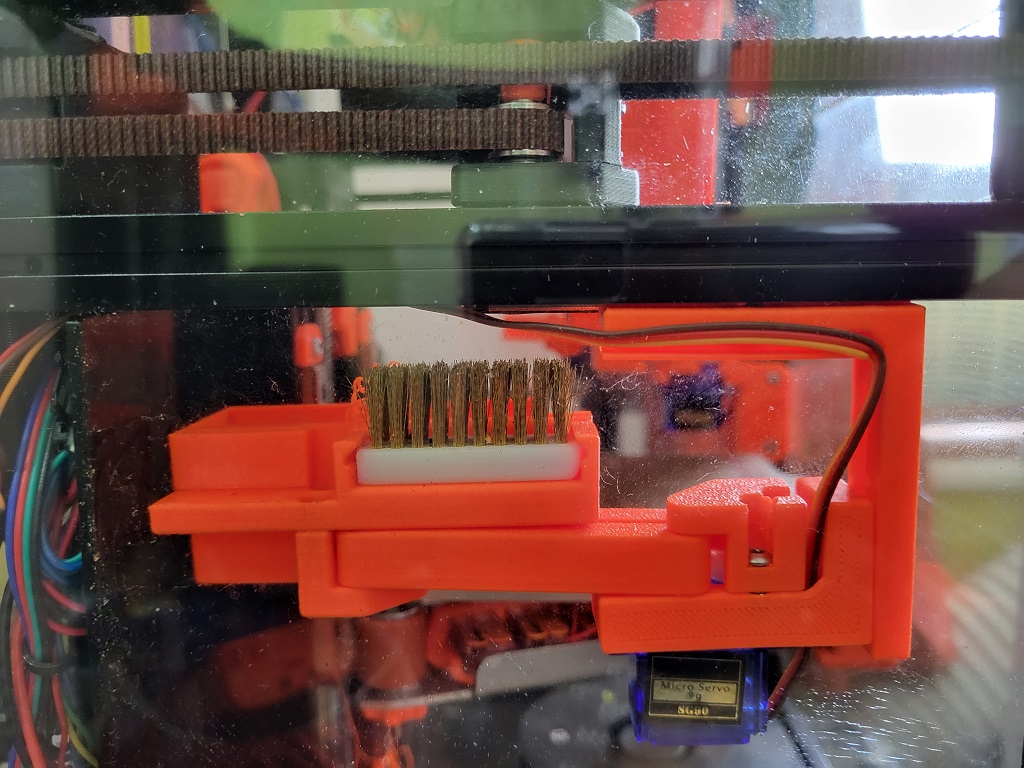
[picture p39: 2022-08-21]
V0/NozzleWiper/images/printerfit.jpg

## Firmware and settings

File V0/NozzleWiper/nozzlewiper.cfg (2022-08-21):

###############################################################################
## NOZZLE WIPER v2 - A nozzle purge bucket and brush for the Voron 0.1
##
## Configuration:
##
## 1.  Set the correct PWM pin that you connected the Orange wire
##     to in the [servo wipeServo] section replacing XXNN
## 2.  Home X, Y and Z axes
## 3.  Lower Z by at least 50mm
## 4.  Run the NW_DEPLOY macro and ensure the servo extends the arm 90 degrees
## 5.  Use the printer controls to move the nozzle so that it is in the centre
##     of the purge bucket on the X and Y axis
## 7.  Run M114 to get the nozzle position and set variable_x and variable_y.
##     If you do not set these values the macro will fail as the defaults are
##     deliberately wrong
## 8.  Move the nozzle into the center of the brush and raise the Nozzle Wiper
##     on the frame mount until the nozzle just rests into the brush. Try not
##     to let the brush touch the sock or it couldwear it out prematurely.
##     Secure the position by lightly tightening the 2 M3x8mm screws on the
##     frame mount
## 9.  Move the nozzle out of the way from the brush and purge bucket
## 10. Run NW_RETRACT and ensure the servo moves the arm back away to the side
##
## Testing:
##
## 1.  Heat the nozzle to the printing temperature of the loaded filament
## 2.  Home all axes
## 3.  Be prepared to hit the Emergency Stop button if things don't go as they
##     should
## 4.  Run NW_CLEAN_NOZZLE
##
## That should be all changes needed. Call the NW_CLEAN_NOZZLE macro from
## the end of your START_PRINT macro to wipe the nozzle clean before printing
###############################################################################

[servo wipeServo]
pin: XXNN
minimum_pulse_width: 0.0005
maximum_servo_angle: 180

[gcode_macro NW_CLEAN_NOZZLE]
gcode:
   {% if "xyz" in printer.toolhead.homed_axes %}
      SAVE_GCODE_STATE NAME=NW_CLEAN_NOZZLE
      G90
      NW_DEPLOY
      NW_PURGE
      NW_WIPE
      NW_RETRACT
      RESTORE_GCODE_STATE NAME=NW_CLEAN_NOZZLE
   {% else %}
      { action_raise_error("Home All Axis First") }
      M117 Home All Axis First
   {% endif %}

[gcode_macro NW_BUCKET_POS]
# Sensible values for variable_x would be 32, but adjust as per the instructions
variable_x: -1000
# Sensible values for variable_y would be around 60, but adjust as per the instructions
variable_y: -1000
# Sensible value for variable_z is 50
variable_z: 50
gcode:
  M118 bucket pos X:{printer["gcode_macro NW_BUCKET_POS"].x} Y:{printer["gcode_macro NW_BUCKET_POS"].y} Z:{printer["gcode_macro NW_BUCKET_POS"].z}

[gcode_macro NW_DEPLOY]
gcode:
    G90
    G0 Z{printer["gcode_macro NW_BUCKET_POS"].z}
    SET_SERVO SERVO=wipeServo ANGLE=15
    G4 P500
    
[gcode_macro NW_RETRACT]
gcode:
    SET_SERVO SERVO=wipeServo ANGLE=120
    SET_SERVO SERVO=wipeServo WIDTH=0 # OFF
    G4 P500

[gcode_macro NW_WIPE]
gcode:
    G90
    G0 Z{printer["gcode_macro NW_BUCKET_POS"].z} F5000
    G0 X{printer["gcode_macro NW_BUCKET_POS"].x} Y{printer["gcode_macro NW_BUCKET_POS"].y - 25} F5000
    {% for wipes in range(1, 4) %}
        G0 Y{printer["gcode_macro NW_BUCKET_POS"].y - 25} F{2000}
        G0 Y{printer["gcode_macro NW_BUCKET_POS"].y - 55} F{2000}
    {% endfor %}
    G0 X60 F5000
    G0 Y60 F5000

[gcode_macro NW_PURGE]
gcode:
    G90
    G0 Z{printer["gcode_macro NW_BUCKET_POS"].z} F5000
    G0 Y{printer["gcode_macro NW_BUCKET_POS"].y+40} F5000
    G0 X{printer["gcode_macro NW_BUCKET_POS"].x}
    G0 Y{printer["gcode_macro NW_BUCKET_POS"].y} F5000
    {% if printer.extruder.temperature >= 180 %}
       M83
       G1 E10 F150
       G1 E-2 F{150 * 750}
       G4 P{2000}
       G92 E0
    {% else %}
      { action_raise_error("Nozzle Temp must be > 180C") }
    {% endif %}

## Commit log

2022-04-12 Toolhead v0.1
    [Door handle.stl, Door hinge - door.stl, Door hinge - frame.stl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]
2022-04-12 Removed unpublished STLs
    [Door handle.stl, Door hinge - door.stl, Door hinge - frame.stl]
2022-04-12 Updates to docs
    [Dragon_Burner_No_Klicky.stl, Dragon_Burner_SlideSwipe.stl, Dragon_Burner_adxl_mount.stl]
2022-04-12 Removed fillets touching bed
    [Dragon_Burner_adxl_mount.stl]
2022-04-13 Fixed fillet on main body
    [Dragon_Burner_NoKlicky.stl, Dragon_Burner_No_Klicky.stl, Dragon_Burner_SlideSwipe.stl]
2022-04-13 Added Dragonfly and Rapido
    [Dragon_Burner_NoKlicky.stl, Dragon_Burner_SlideSwipe.stl, Rapido_Burner_NoKlicky_Untested.stl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]
2022-04-13 Updated docs
    [Dragonfly_Burner_NoKlicky.stl, Dragonfly_Burner_SlideSwipe.stl]
2022-04-13 Dragonfly updates
    [Dragonfly_Burner_NoKlicky.stl, Dragonfly_Burner_SlideSwipe.stl]
2022-04-13 Fixed clearance to socks on Rapido and Dragonfly
    [Dragonfly_Burner_NoKlicky.stl, Dragonfly_Burner_SlideSwipe.stl, Rapido_Burner_NoKlicky.stl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]
2022-04-16 New ducts and better filament alignment
    [Dragon_Burner_NoKlicky.stl, Dragon_Burner_SlideSwipe.stl, Dragonfly_Burner_NoKlicky.stl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]
2022-04-19 New ducts and heatbreak thermistor
    [Dragon_Burner_NoKlicky.stl, Dragon_Burner_SlideSwipe.stl, Dragonfly_Burner_NoKlicky.stl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]
2022-04-21 Added Klicky and screwless 3010 mount
    [Dragon_Burner_ADXLMount.stl, Dragon_Burner_FanNubs.stl, Dragon_Burner_Klicky.stl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]
2022-04-27 Added E3D Revo Voron hotend support
    [Dragon_Klicky.stl, Dragon_NoProbe.stl, Dragon_SlideSwipe.stl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]
2022-05-04 added klipper config file
    [nozzlewiper.cfg]
2022-05-07 Added wire exit for Klicky mount
    [Dragon_Klicky.stl]
2022-05-07 Wire exit for all hotends with Klicky
    [Dragonfly_BMO_Klicky.stl, Rapido_HF_Klicky.stl, Revo_Voron_Klicky.stl]
2022-05-08 Removeable Fan Ducts
    [Dragon.stl, Dragon_Klicky.stl, Dragon_NoProbe.stl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]
2022-05-08 Fix for Dragon toolhead
    [Dragon.stl]
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2022-05-11 Updated Unklicky fan duct to be the same as the rest
    [FanDuct_Right_Klicky.stl]
2022-05-21 Added bridging supports to Klicky fan ducts
    [FanDuct_Right_Klicky.stl, FanDuct_Right_Klicky_RapidoHF.stl]
2022-06-03 Additional cowls
    [Cowl_Klicky.stl, Cowl_NoProbe.stl, Cowl_SlideSwipe.stl]
2022-06-03 Doc updates
    [ADXL_Mount.stl]
2022-06-04 Added support for Voron PocketWatch
    [Guts_p2_x1.stl]
2022-06-05 Added cable exit hole in Klicky cowl
    [Cowl_Klicky.stl]
2022-06-05 Updated fan ducts
    Easier to print fan ducts and magnet helper for ZeroClick
    [FanDuct_Left.stl, FanDuct_Left_RapidoHF.stl, FanDuct_Left_ZeroClick.stl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]
2022-06-05 Added cable ducts to cowls
    [Cowl_Klicky.stl, Cowl_NoProbe.stl, Cowl_SlideSwipe.stl]
2022-06-05 Moved zip-ties from cowls to hotend mounts
    [Cowl_Klicky.stl, Cowl_NoProbe.stl, Cowl_SlideSwipe.stl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]
2022-06-07 Neopixels and adxl mount added
    [ADXL_Mount.stl, Cowl_Klicky.stl, Cowl_NoProbe.stl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]
2022-06-08 Release update to all STLS, images and docs
    [Cowl_Klicky.stl, Cowl_NoProbe.stl, Cowl_SlideSwipe.stl]
2022-06-13 Fixed the Revo Voron mount
    [Revo_Voron_mount.stl]
2022-06-13 Added Rapido HF mount
    [RapidoHF_mount.stl]
2022-06-18 Test Rapido HF toolheads for Dragon Burner
    [RapidoHF_Long_Test.stl, RapidoHF_Short_Test.stl]
2022-06-24 RoundHouse Extruder
    [LGX_Lite_mount.stl, RoundHouse_Back.stl, RoundHouse_Front.stl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]
2022-06-24 Updates RoundHouse STLs
    [RoundHouse_Back.stl, RoundHouse_Front.stl]
2022-06-26 Updated extruders
    [MiniMouse Back.stl, MiniMouse Front.stl, MiniMouse Lever.stl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]
2022-06-30 MiniMouse updates
    [MiniMouse_Back.stl, MiniMouse_Front.stl]
2022-06-30 RoundHouse updates
    [RoundHouse_Back.stl, RoundHouse_Front.stl]
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2022-07-03 5015 Toolhead ZeroClick support
    [Cowl_ZeroClick.stl, ZeroClick_mount.stl]
2022-07-11 Added NozzleWipe STEP CAD
    [NozzleWiper.step]
2022-07-12 Updated Body Quarters and STEP file
    [Body_Q3.stl, Body_Q4.stl]
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2022-07-15 Docs and STEP for runoutunklicky
    [RunoutUnKlicky.step]
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2022-07-18 Fix roller.stl dimensions
    [Roller.stl]
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2022-07-24 Update nozzlewiper.cfg
    Fixed typo in instruction text
    [nozzlewiper.cfg]
2022-07-24 Updated NozzleWiper STLs and STEP
    [Allinone.stl, Arm1.stl, Arm2.stl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]
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2022-07-25 Fixed printability issues
    [Allinone.stl, Brush_Carrier.stl, Carrier_Joint.stl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]
2022-07-28 Roundhouse redesign STLs
    [Back.stl, Front.stl, Guidler.stl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]
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2022-07-30 Fixed missing logo
    [Cowl_Klicky.stl, Cowl_NoProbe.stl, Cowl_SlideSwipe.stl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]
2022-08-05 Fixed orientation
    [Back.stl, Front.stl, Guidler.stl]
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2022-08-05 Updated Docs and sample macros
    [runoutunklicky.cfg]
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2022-08-08 beta v3 updates
    Fixed logo chamfers
    [Cowl_Klicky.stl, Cowl_MiniSlideSwipe.stl, Cowl_NoProbe.stl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]
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2022-08-09 Updated cowls and hotend mounts
    [Back.stl, Cowl_Klicky.stl, Cowl_MiniSlideSwipe.stl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]
2022-08-09 Updated beta v3 cowls
    [Cowl_Klicky.stl, Cowl_MiniSlideSwipe.stl, Cowl_NoProbe.stl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]
2022-08-10 Updated beta v3 ducts
    [Cowl_Klicky.stl, Cowl_MiniSlideSwipe.stl, Cowl_NoProbe.stl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]
2022-08-10 Added missing chamfers
    [Front.stl]
2022-08-11 Improved fan cover tolerances for a tighter fit
    [Fan_Cover.stl]
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2022-08-15 5015 Toolhead v3 Release
    [ADXL_Mount.stl, Cowl_Klicky.stl, Cowl_MiniSlideSwipe.stl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]
2022-08-16 Dragon Burner v2 Beta
    [ADXL_Mount.stl, Cowl_Klicky.stl, Cowl_NoProbe.stl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]
2022-08-16 DB b2 cowl updates
    [Cowl_Klicky.stl, Cowl_NoProbe.stl, Cowl_SlideSwipe.stl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]
2022-08-19 NF Crazy hotend mod
    [Cowl_NoProbe_NFCrazy.stl, NFCrazy_Mount.stl]
2022-08-21 nozzle wiper v2 beta
    [Bucket.stl, Carrier_Joint.stl, Frame_Mount.stl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]
2022-08-22 improved db v2 beta fan duct space
    [Cowl_Klicky.stl, Cowl_NoProbe.stl, Cowl_SlideSwipe.stl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]
2022-08-22 Improved dragon burner v2 beta hotend space
    [Cowl_Klicky.stl, Cowl_NoProbe.stl, Cowl_SlideSwipe.stl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]
2022-08-22 Correct db v2 beta stl orientation
    [Cowl_Klicky.stl, Cowl_NoProbe.stl, Cowl_SlideSwipe.stl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]
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2022-08-26 Updates Dragon Burner beta v2 STLs
    [ADXL_Mount.stl, Cowl_Klicky.stl, Cowl_NoProbe.stl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]
2022-08-27 Dragon Burner v2
    [ADXL_Mount.stl, Cowl_Klicky.stl, Cowl_NoProbe.stl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]
2022-08-28 NF Crazy and Orbiter2 support added
    [Cowl_Klicky.stl, Cowl_NoProbe.stl, Cowl_SlideSwipe.stl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]
2022-08-28 Updated NF Crazy mounts
    [NF_Crazy_Mount.stl]
2022-08-29 Dragon Burner Orbiter v1.5 support added
    [Dragon_Mount.stl, Dragonfly_Mount.stl, NF_Crazy_Mount.stl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]
2022-08-29 Fixed part orientation
    [NF_Crazy_Mount.stl]
2022-08-29 Fixed incorrect offset on the back
    [Back.stl]
2022-08-30 Updated extruder and hotend mounts to maximise space
    [Dragon_mount.stl, Dragonfly_mount.stl, Extruder_Mount.stl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]
2022-08-30 Improve motor gear meshing
    [Back.stl, Front.stl]
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2022-09-02 Improved tolerances and added third back screw
    [Back.stl, Front.stl]
2022-09-04 Rapid Burner Beta
    [ADXL_Mount.stl, Cowl_Klicky.stl, Cowl_NoProbe.stl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]
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2022-09-16 5015 Toolhead v4 release
    [ADXL_Mount.stl, Cowl_Klicky.stl, Cowl_MiniSlideSwipe.stl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]
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2022-09-22 Released bowden mounts for all toolheads
    [Bowden_Mount.stl]
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2022-09-30 Updated all cowlings to help fix screws loosening over time
    [Cowl_Klicky.stl, Cowl_NoProbe.stl, Cowl_SlideSwipe.stl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]
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
